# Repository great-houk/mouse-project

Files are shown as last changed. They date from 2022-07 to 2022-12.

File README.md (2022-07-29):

# Custom Mouse V1.0

This project is an all contains every piece you would need to fully order, assemble, and program a completely open source mouse.

This is only the first version of this mouse, and the end goal of this project is no where near complete. However, this first version does 100% work 90% of the time, so the inital goal of making a mouse is complete. In fact, I'm using it to write this readme. Pretty neat.

My immediate goal is to implement the wireless protocol over the SR1020 radio.

Future versions of this project won't use a barebones $15 dollar mouse off of amazon, and will have much higher quality everything, while also hopefully being cheaper. I used a lot of parts on this, like the MAX32625, because they looked cool. The 32625 has a one of a kind PMU, which is something like another set of super low power cores you can manually program through assembly. While this seems awesome at first, and like the perfect tool to reach extra efficient power targets, in the end the sensor draws >20mW anyway, so the difference of ~1-2mW the PMU provides is useless, and so it the extra cost.

# Notes for making your own

This is the mouse I bought and used as a base: [Amazon Link](https://www.amazon.com/gp/product/B07ZHFCM43/ref=ppx_yo_dt_b_search_asin_title?ie=UTF8&th=1)

For obtaining the other parts:
1. Most mouse parts can be desoldered from the mouse itself. I only bought one switch for the dongle off of digikey.
2. All other digital parts except the sensor can be obtained from digikey for reasonable prices, and the objects in the Kicad PCB should have digikey links associated with them already.
3. The mouse sensor is hard to get. If you are a student like me, you might be able to get a free sample from Pixart. If you aren't there are a couple of ebay postings or other second hand sellers which might offer them, but they take a while (>month normally) to ship. Pixart does offer to sell the sensors directly, but there is a minimum order quantity of 25.
4. I used JLCPCB to obtain the PCB. I had them make a stencil as well, in order to greatly simply to soldering process. For anyone in the US, chances are JLC is your best bet, for Europe, I've heard of other cheap PCB manufacturers which might do a better job, as long as the shipping isn't prohibitively expensive.
5. Programming the MCU. I used the [MCU Link](https://www.nxp.com/design/microcontrollers-developer-resources/mcu-link-debug-probe:MCU-LINK) with OpenOCD to program the chip, which had all the features I ended up needing. Maxim offers a custom fork of OpenOCD which comes the neccessary files for uploading to the MAX32625, and I made a simple custom file for the MCU Link, which is inside of the mouse folder. You need to place that file in the OpenOCD board config directory, and most online tutuorials should cover that.

The PCB is specifically designed around fitting in the mouse, and even then there were some mistakes I made. Most notably, the top right post hole was misplaced, so that needs to be cut flush so the PCB can rest flat. The antenna also sticks out the side, so you need to cut some small segments off of the casing in order to have it fit. Finally, the USB-C port is in a slightly lower and different place, so you need to cut the sides of the USB port out to have it fit and be accessible.

It took me many tries to assemble this properly, partially because it was my first time using solder past (which by the way is 100% what you need to use to solder this), and partially because there are no good resources out there for solder of this kind, at least that I could find. If you order the PCB from JLCPCB like I did, make sure to get a stencil, as it will make everything signifigantly easier. There is no need to order a stencil for the back, however, that only requires some careful soldering.

The most important parts when assembling the board are
1. Make sure you spread the paste over the stencil the fewest possible times, preferably in one strong, slow swipe. A good solder paste application makes this process signifigantly easier.
2. Don't leave the paste sitting for too long. You can take your time placing the parts, but after around 2-3 hours the paste will start drying and harden, making parts have a signifigantly higher risk of being blown away when using the heat gun.
3. Make sure to not have the temps too high. I broke my first few boards by creating shorts through burned flux. Don't do what I did.

And that's mostly it. There are other resources out there to help with the specifics, but that covers most of the general details.

# Project Structure

Each folder has it's own README which describes what it does, how it works, and how to use it, except the PCB.

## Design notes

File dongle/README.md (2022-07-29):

# Dongle

When the wireless protocal is implemented, this folder will serve as the source code for the dongle that communicates with the mouse, since no current PCs have UWB built in by default, afaik.

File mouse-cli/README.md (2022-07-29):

# Mouse CLI

Mouse CLI is a command line tool to interface with the mouse and it's custom command protocol. It has various commands, like bat to check battery voltage, or lorem-ipsum to check that both devices are working properly. 

In order to use, check the various commands available with the help command. This is a clap based CLI tool, so everything works like you would expect a normal CLI would.

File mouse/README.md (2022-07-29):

# Mouse

This is the main code repository for the mouse. This is what runs on the mouse and does literally everything. This directory contains several sub crates all of which implement and provide basic APIs to various MAX32625 features which where required to build this project. To change any functionality with the mouse or fix any bugs, this is where you want to be.

Goals:
1. The scroll wheel is currently rather buggy at any speed except medium, so possible come up with a better way to debounce/denoise the signals coming from the GPIOs.
2. Refactor, refactor, refactor. While the code in here isn't horrible, it isn't great. Many things could be rewritten in better and more efficient ways, especially the USB implementation.

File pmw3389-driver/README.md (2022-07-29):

# PMW3389 Driver

Like the SR1020 Driver, this provides a more generic implimentation of various methods used to communicate with and use the PMW3389 Mouse Sensor. There are many details in here which are limited because of the NDA which I signed to access them, so in order to understand why some things are the way they are, contact Pixart throught their support page to gain access to the datasheet and firmware.

For example, the ROM file is behind an NDA, so it is not included here, but is required for the code to compile.

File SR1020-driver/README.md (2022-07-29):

# SR1020

A currently not implemented driver for the SR1020 UWB radio. My goal for this is to draw inspiration from the [official spark SDK](https://www.sparkmicro.com/sdk-docs/), but provide lower level access to the hardware. It should be agnostic to whatever networking protocol you decide to implement on top of it. There is also an overall goal for this project to move everything from custom traits to embedded_hal traits, but currently I don't know if that's worth it.

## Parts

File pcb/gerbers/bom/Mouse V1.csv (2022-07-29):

Id | Designator | Package | Quantity | Designation | Supplier and ref
1 | C9,C3,C48,C46,C8,C47,C5,C30,C1,C45,C2,C7,C4,C29,C31,C10,C6 | C_0603_1608Metric | 17 | 1uF
2 | L5,L4 | L_0603_1608Metric | 2 | 180nH
3 | C25,C21,C23,C11 | C_0603_1608Metric | 4 | 4.7uF 10V
4 | R30,R21,R20,R19 | R_0603_1608Metric | 4 | 100K
5 | C41,C35 | C_0603_1608Metric | 2 | 680pF C0G NP0
6 | R6,R5,R3 | R_0603_1608Metric | 3 | 200
7 | R14 | R_0603_1608Metric | 1 | 10K
8 | C12,C28,C16,C17,C22,C27,C26,C37,C19 | C_0603_1608Metric | 9 | 10uF 10V
9 | U1,U6 | TSOT-23-5 | 2 | S-1740C33-M5T1U4
10 | Y2,Y3,Y1 | Crystal_SMD_3215-2Pin_3.2x1.5mm | 3 | ABS07-120-32.768KHZ-T
11 | FB2,FB3,FB5,FB1 | L_0805_2012Metric | 4 | FBMJ2125HS250NT
12 | U8,U5 | QFN-28-1EP_4x4mm_P0.4mm_EP2.6x2.6mm | 2 | SR1020-28QFN-TR
13 | R28,R33 | R_0603_1608Metric | 2 | 2.2M +- 1%
14 | R17,R18 | R_0603_1608Metric | 2 | 1M
15 | R16,R15 | R_0603_1608Metric | 2 | 5.1K
16 | C33,C42,C34,C43 | C_0603_1608Metric | 4 | 10pF
17 | R31,R32,R29 | R_0603_1608Metric | 3 | 390K +- 5%
18 | U4 | QFN40P400X400X80-29N | 1 | MAX8819CETI+
19 | C44,C38,C14,C13,C20,C15,C39,C18,C32 | C_0603_1608Metric | 9 | 100nF 10V
20 | R23 | R_0603_1608Metric | 1 | 120K
21 | U7 | SOIC-14_3.9x8.7mm_P1.27mm | 1 | ATSAMD11C14A-SS
22 | L2,L3,L1 | L_Taiyo-Yuden_MD-2020 | 3 | 4.7uH
23 | C36,C40 | C_0603_1608Metric | 2 | 68pF C0G NP0
24 | D5,D4 | CM1231-02SO | 2 | CM1231
25 | R26,R27 | R_0603_1608Metric | 2 | 470K
26 | R24 | R_0603_1608Metric | 1 | 80.6K
27 | U2 | MAX32625ITKL&plus_ | 1 | MAX32625
28 | R13 | R_0603_1608Metric | 1 | 13
29 | 3V3 | TestPoint_Pad_D1.0mm | 1 | 3.3V Test Point
30 | SW10 | SW_SPST_B3U-1000P-B | 1 | SW_Push
31 | C24 | C_0603_1608Metric | 1 | 2.2uF
32 | R25 | R_0603_1608Metric | 1 | 20K
33 | R22 | R_0603_1608Metric | 1 | 3K

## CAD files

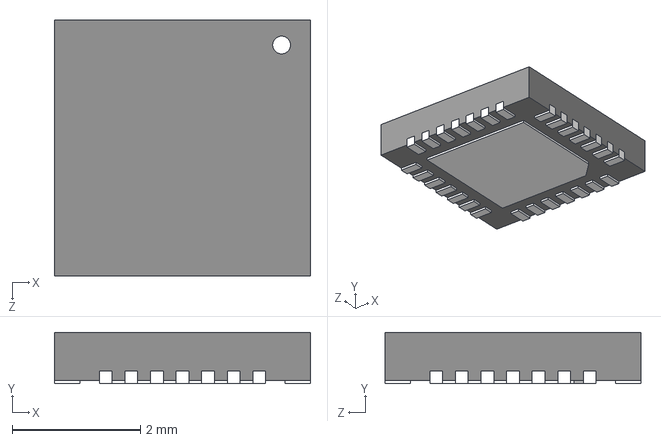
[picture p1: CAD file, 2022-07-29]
pcb/footprints/MAX8819/MAX8819CETI_.step
4.00 x 0.8 x 4.00 mm

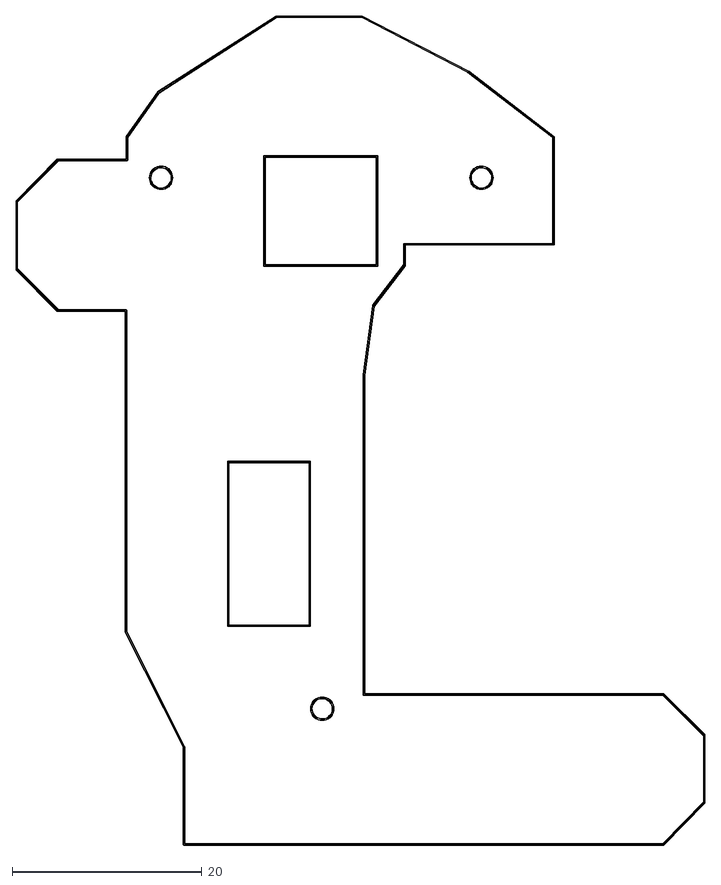
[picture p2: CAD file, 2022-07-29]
pcb/gerbers/gerbers/Mouse V1-Edge_Cuts.dxf
72.7 x 87.5

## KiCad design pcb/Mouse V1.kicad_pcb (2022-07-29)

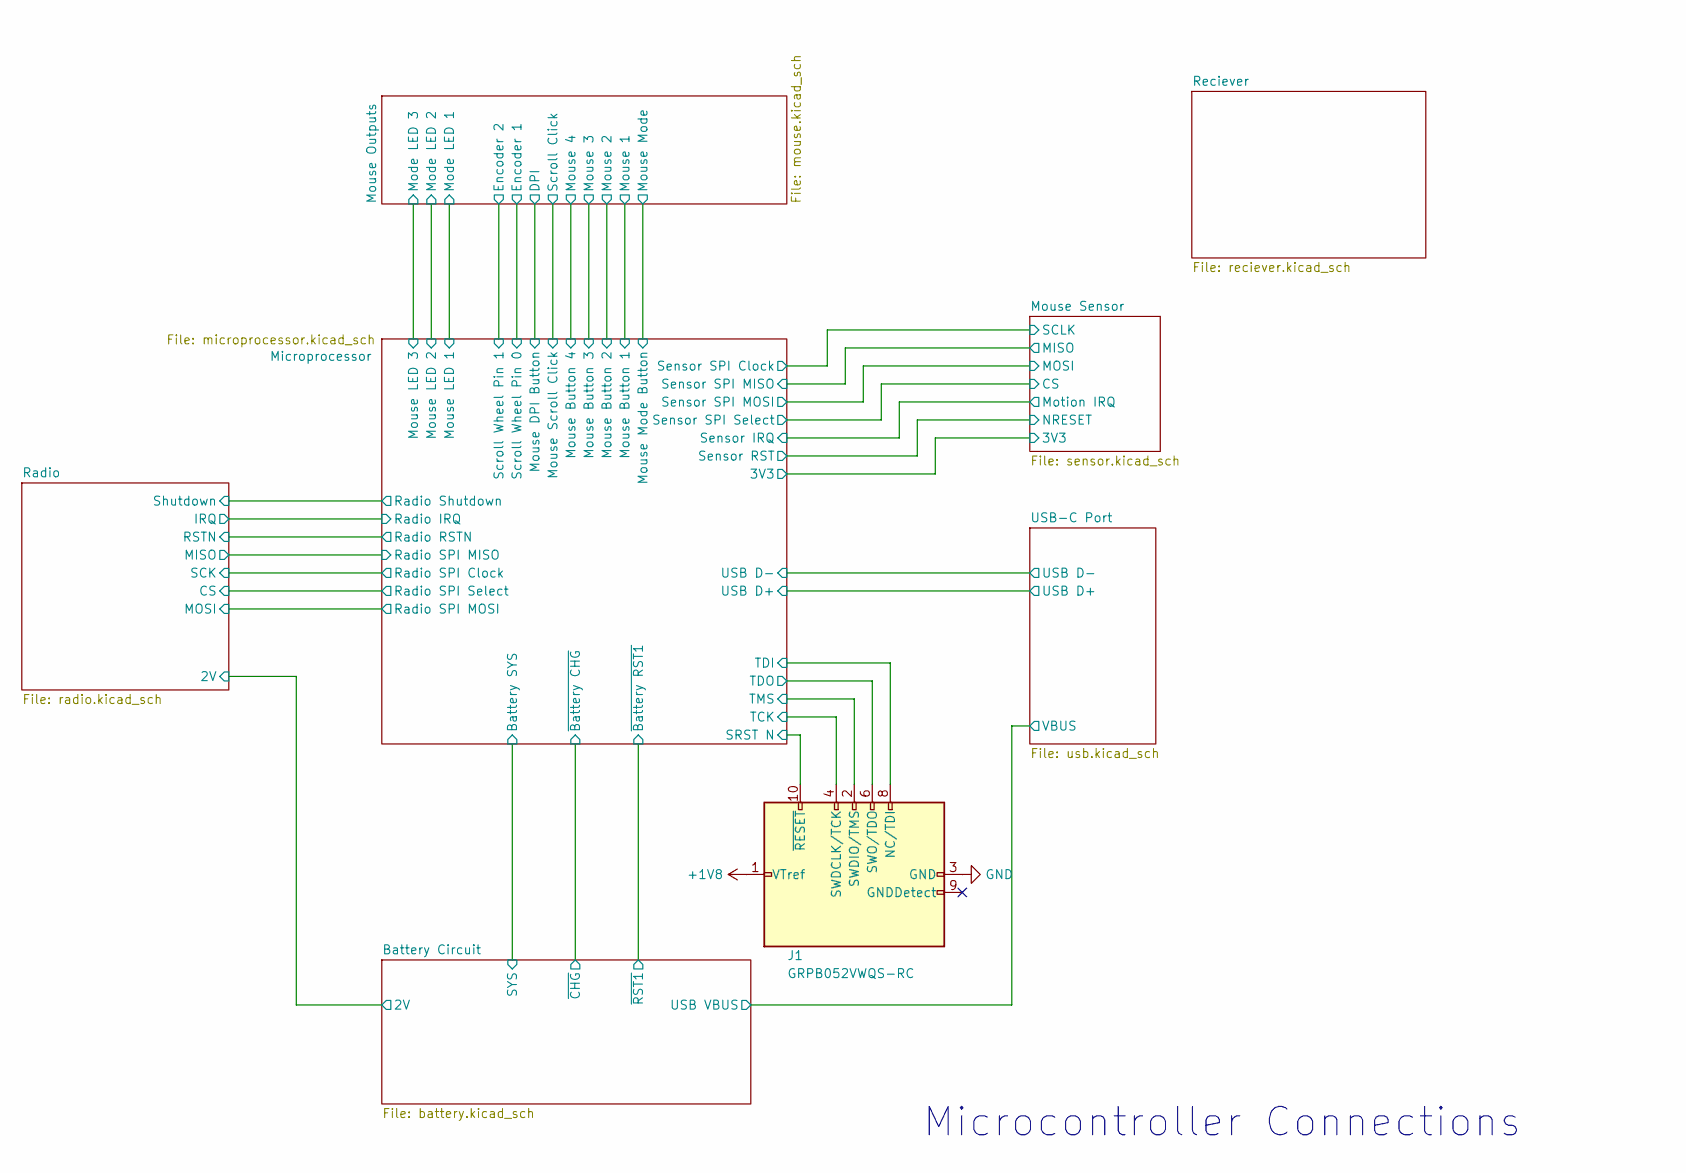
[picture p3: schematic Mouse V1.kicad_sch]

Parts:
J1: GRPB052VWQS-RC; PinHeader_2x05_P1.27mm_Vertical_SMD; DIGIKEY GRPB052VWQS-RC

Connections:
+1V8: J1.1 (VTref); also elsewhere on the board
/Microprocessor/SRST N: J1.10 (~RESET); also elsewhere on the board
/Microprocessor/TCK: J1.4 (SWDCLK/TCK); also elsewhere on the board
/Microprocessor/TDI: J1.8 (NC/TDI); also elsewhere on the board
/Microprocessor/TDO: J1.6 (SWO/TDO); also elsewhere on the board
/Microprocessor/TMS: J1.2 (SWDIO/TMS); also elsewhere on the board
GND: J1.3 (GND), J1.5 (GND); also elsewhere on the board

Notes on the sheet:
Microcontroller Connections

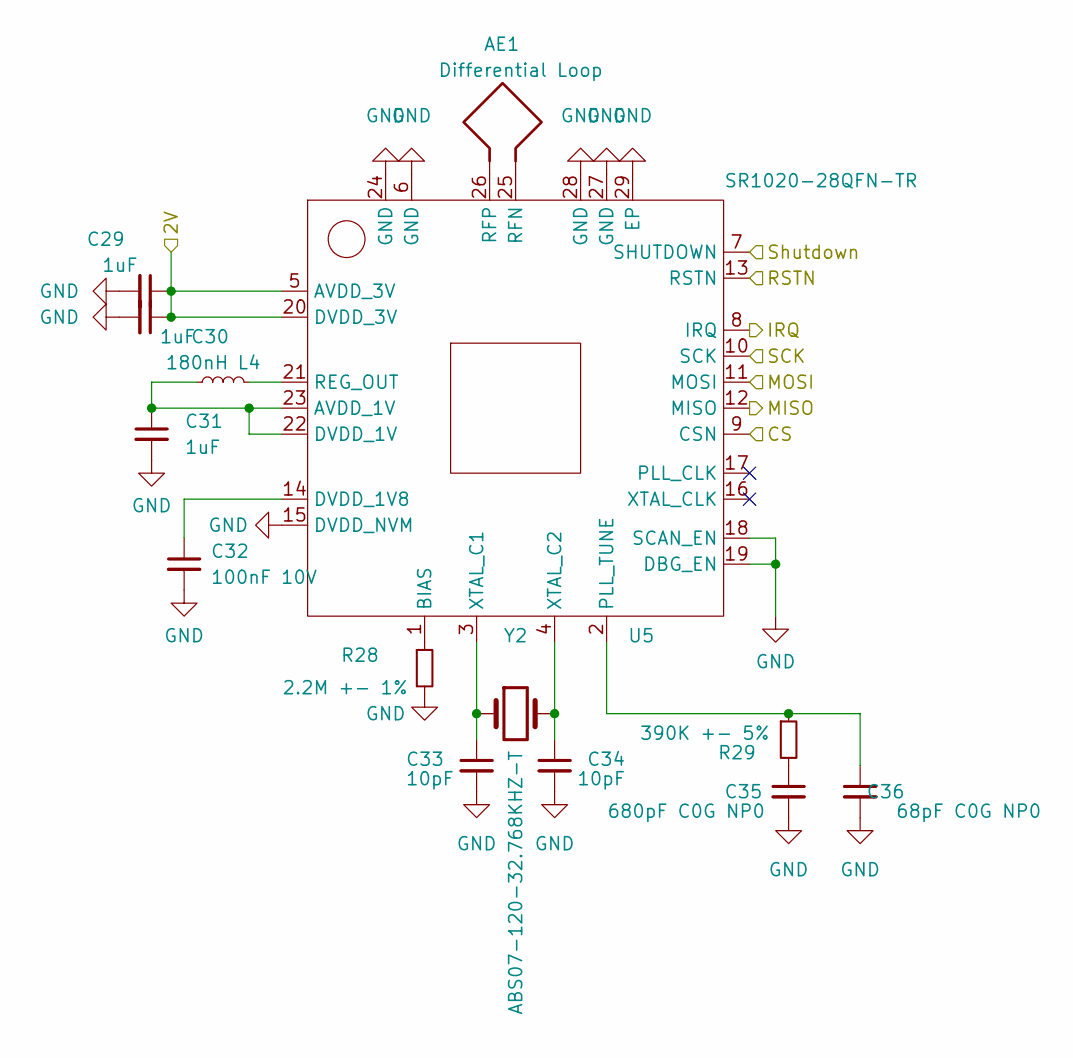
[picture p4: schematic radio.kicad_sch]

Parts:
AE1: Differential Loop; SR1020 Antenna Vivaldi
C29, C30, C31: 1uF; C_0603_1608Metric; DIGIKEY CL10A105KA8NNNC
C32: 100nF 10V; C_0603_1608Metric; DIGIKEY CL10B104KB8NNWC
C33, C34: 10pF; C_0603_1608Metric; DIGIKEY 06035A100JAT2A
C35: 680pF C0G NP0; C_0603_1608Metric; DIGIKEY 0603N681J500CT
C36: 68pF C0G NP0; C_0603_1608Metric; DIGIKEY CL10C680JB8NNNC
L4: 180nH; L_0603_1608Metric; DIGIKEY MLJ1608WR18JT000
R28: 2.2M +- 1%; R_0603_1608Metric; DIGIKEY RC0603FR-072M2L
R29: 390K +- 5%; R_0603_1608Metric; DIGIKEY RMCF0603JT390K
U5: SR1020-28QFN-TR; QFN-28-1EP_4x4mm_P0.4mm_EP2.6x2.6mm; DIGIKEY SR1020-28QFN-TR
Y2: ABS07-120-32.768KHZ-T; Crystal_SMD_3215-2Pin_3.2x1.5mm; DIGIKEY ABS07-120-32.768KHZ-T

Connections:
/Battery Circuit/2V: C29.1, C30.1, U5.5 (AVDD_3V), U5.20 (DVDD_3V); also elsewhere on the board
/Microprocessor/Radio IRQ: U5.8 (IRQ); also elsewhere on the board
/Microprocessor/Radio RSTN: U5.13 (RSTN); also elsewhere on the board
/Microprocessor/Radio SPI Clock: U5.10 (SCK); also elsewhere on the board
/Microprocessor/Radio SPI MISO: U5.12 (MISO); also elsewhere on the board
/Microprocessor/Radio SPI MOSI: U5.11 (MOSI); also elsewhere on the board
/Microprocessor/Radio SPI Select: U5.9 (CSN); also elsewhere on the board
/Microprocessor/Radio Shutdown: U5.7 (SHUTDOWN); also elsewhere on the board
GND: C29.2, C30.2, C31.2, C32.2, C33.2, C34.2, C35.2, C36.2, R28.2, U5.6 (GND), U5.15 (DVDD_NVM), U5.18 (SCAN_EN), U5.19 (DBG_EN), U5.24 (GND), U5.27 (GND), U5.28 (GND), U5.29 (EP); also elsewhere on the board
unnamed: AE1.1, U5.26 (RFP)
unnamed: AE1.2, U5.25 (RFN)
unnamed: C31.1, L4.1, U5.22 (DVDD_1V), U5.23 (AVDD_1V)
unnamed: C32.1, U5.14 (DVDD_1V8)
unnamed: C33.1, U5.3 (XTAL_C1), Y2.1
unnamed: C34.1, U5.4 (XTAL_C2), Y2.2
unnamed: C35.1, R29.2
unnamed: C36.1, R29.1, U5.2 (PLL_TUNE)
unnamed: L4.2, U5.21 (REG_OUT)
unnamed: R28.1, U5.1 (BIAS)

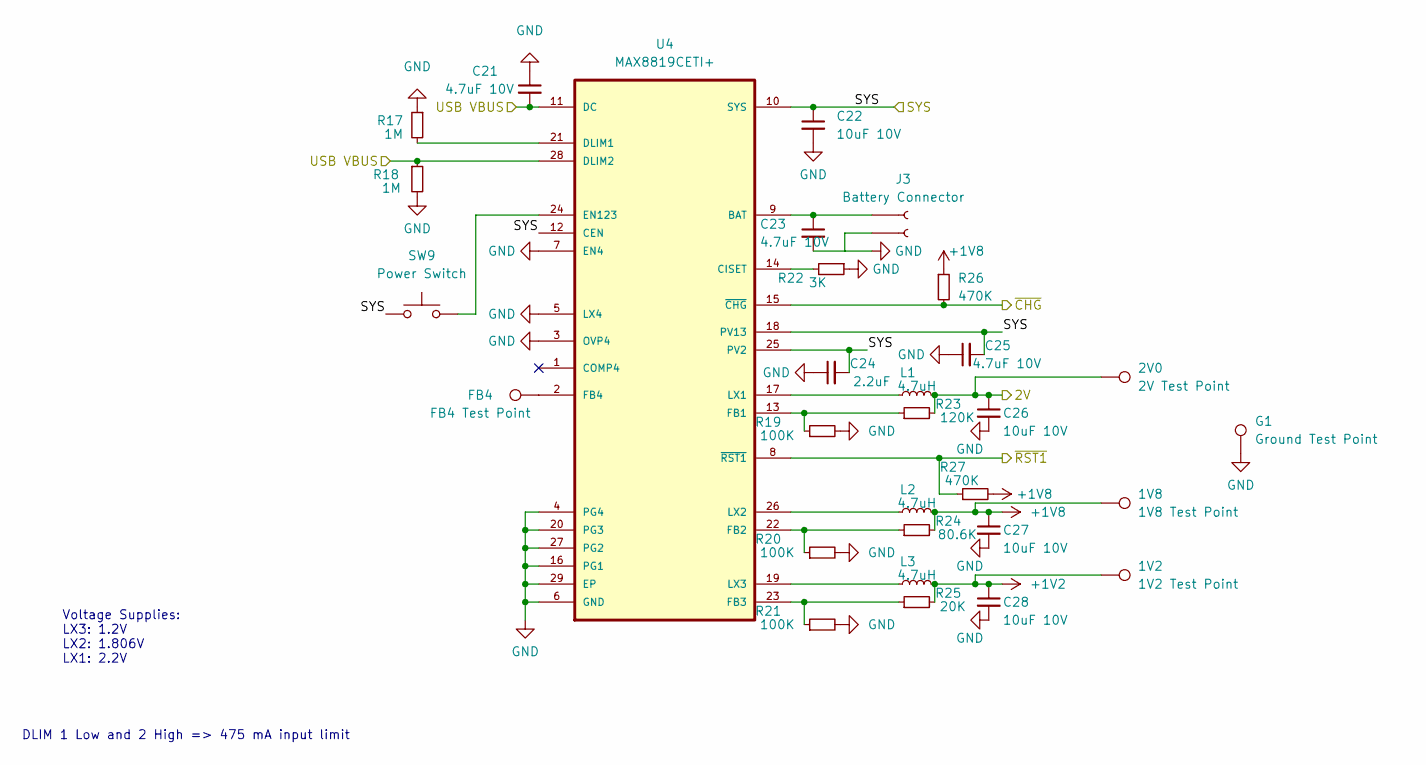
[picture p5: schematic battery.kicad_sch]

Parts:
1V2: 1V2 Test Point; TestPoint_Pad_D1.0mm
1V8: 1V8 Test Point; TestPoint_Pad_D1.0mm
2V0: 2V Test Point; TestPoint_Pad_D1.0mm
C21, C23, C25: 4.7uF 10V; C_0603_1608Metric; DIGIKEY CL10A475KP8NNNC
C22, C26, C27, C28: 10uF 10V; C_0603_1608Metric; DIGIKEY 0603ZD106KAT2A
C24: 2.2uF; C_0603_1608Metric; DIGIKEY CL10A225KP8NNNC
FB4: FB4 Test Point; TestPoint_Pad_D2.0mm
G1: Ground Test Point; TestPoint_Pad_D1.0mm
J3: Battery Connector; JST_PH_B2B-PH-K_1x02_P2.00mm_Vertical
L1, L2, L3: 4.7uH; L_Taiyo-Yuden_MD-2020; DIGIKEY VLS201612CX-4R7M-1
R17, R18: 1M; R_0603_1608Metric; DIGIKEY RMCF0603FT1M00
R19, R20, R21: 100K; R_0603_1608Metric; DIGIKEY RMCF0603FT100K
R22: 3K; R_0603_1608Metric; DIGIKEY RMCF0603JT3K00
R23: 120K; R_0603_1608Metric; DIGIKEY RMCF0603FT120K
R24: 80.6K; R_0603_1608Metric; DIGIKEY RMCF0603FT80K6
R25: 20K; R_0603_1608Metric; DIGIKEY RMCF0603FT20K0
R26, R27: 470K; R_0603_1608Metric; DIGIKEY RMCF0603JT470K
SW9: Power Switch; SW_SPDT_PCM12; DIGIKEY Have
U4: MAX8819CETI+; QFN40P400X400X80-29N; DIGIKEY MAX8819CETI+

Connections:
+1V2: 1V2.1, C28.1, L3.2, R25.2; also elsewhere on the board
+1V8: 1V8.1, C27.1, L2.2, R24.2, R26.1, R27.2; also elsewhere on the board
/Battery Circuit/2V: 2V0.1, C26.1, L1.2, R23.2; also elsewhere on the board
/Battery Circuit/SYS: C22.1, C24.2, C25.2, SW9.1, U4.10 (SYS), U4.12 (CEN), U4.18 (PV13), U4.25 (PV2); also elsewhere on the board
/Battery Circuit/USB VBUS: C21.2, R18.1, U4.11 (DC), U4.28 (DLIM2); also elsewhere on the board
/Battery Circuit/~CHG: R26.2, U4.15 (~CHG); also elsewhere on the board
/Battery Circuit/~RST1: R27.1, U4.8 (~RST1); also elsewhere on the board
GND: C21.1, C22.2, C23.2, C24.1, C25.1, C26.2, C27.2, C28.2, G1.1, J3.1, R17.1, R18.2, R19.2, R20.2, R21.2, R22.1, U4.3 (OVP4), U4.4 (PG4), U4.5 (LX4), U4.6 (GND), U4.7 (EN4), U4.16 (PG1), U4.20 (PG3), U4.27 (PG2), U4.29 (EP); also elsewhere on the board
unnamed: C23.1, J3.2, U4.9 (BAT)
unnamed: FB4.1, U4.2 (FB4)
unnamed: L1.1, U4.17 (LX1)
unnamed: L2.1, U4.26 (LX2)
unnamed: L3.1, U4.19 (LX3)
unnamed: R17.2, U4.21 (DLIM1)
unnamed: R19.1, R23.1, U4.13 (FB1)
unnamed: R20.1, R24.1, U4.22 (FB2)
unnamed: R21.1, R25.1, U4.23 (FB3)
unnamed: R22.2, U4.14 (CISET)
unnamed: SW9.2, U4.24 (EN123)

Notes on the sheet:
DLIM 1 Low and 2 High => 475 mA input limit
Voltage Supplies: LX3: 1.2V LX2: 1.806V LX1: 2.2V

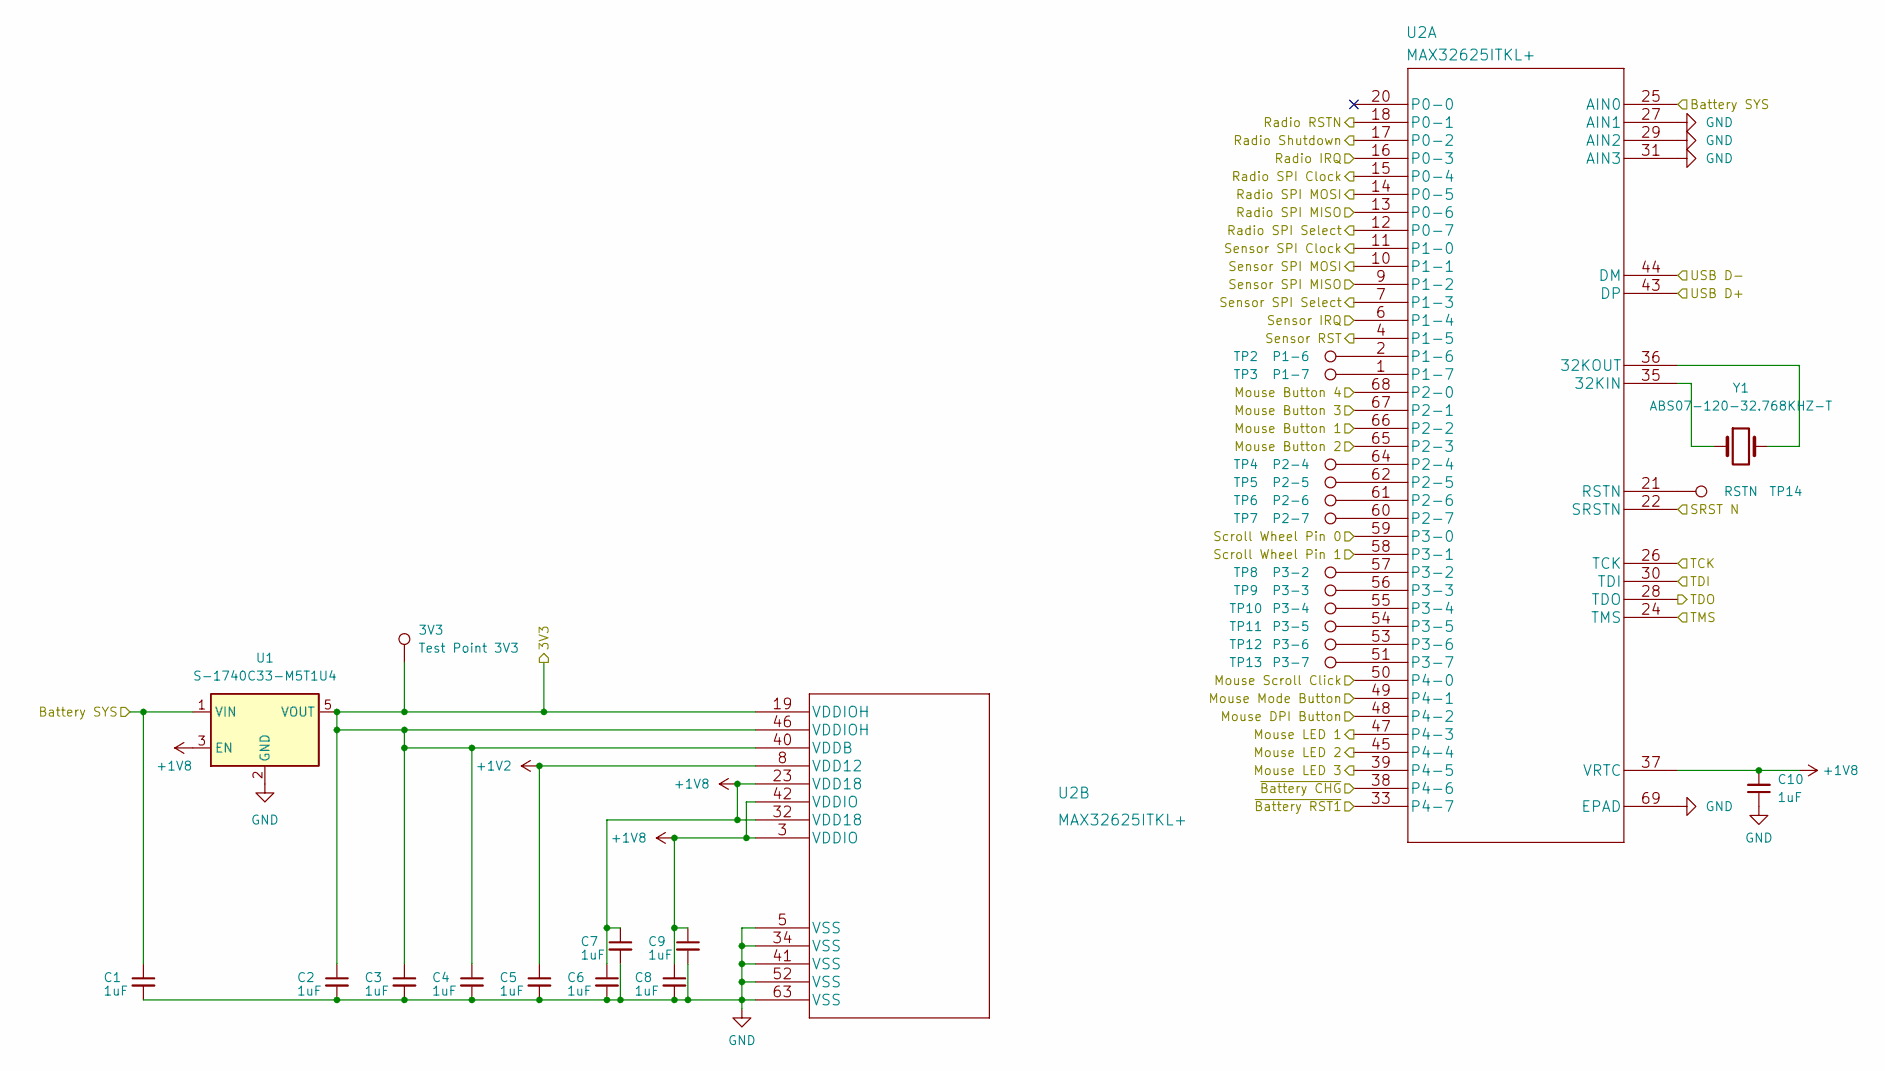
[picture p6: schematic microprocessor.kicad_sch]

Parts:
3V3: Test Point 3V3; TestPoint_Pad_D1.0mm
C1, C2, C3, C4, C5, C6, C7, C8, C9, C10: 1uF; C_0603_1608Metric; DIGIKEY CL10A105KA8NNNC
TP2: P1-6; TestPoint_Pad_D1.0mm
TP3: P1-7; TestPoint_Pad_D1.0mm
TP4: P2-4; TestPoint_Pad_D1.0mm
TP5: P2-5; TestPoint_Pad_D1.0mm
TP6: P2-6; TestPoint_Pad_D1.0mm
TP7: P2-7; TestPoint_Pad_D1.0mm
TP8: P3-2; TestPoint_Pad_D1.0mm
TP9: P3-3; TestPoint_Pad_D1.0mm
TP10: P3-4; TestPoint_Pad_D1.0mm
TP11: P3-5; TestPoint_Pad_D1.0mm
TP12: P3-6; TestPoint_Pad_D1.0mm
TP13: P3-7; TestPoint_Pad_D1.0mm
TP14: RSTN; TestPoint_Pad_D1.0mm
U1: S-1740C33-M5T1U4; TSOT-23-5; DIGIKEY S-1740C33-M5T1U4
U2: MAX32625ITKL+; MAX32625ITKL&plus_; DIGIKEY MAX32625ITKL+
Y1: ABS07-120-32.768KHZ-T; Crystal_SMD_3215-2Pin_3.2x1.5mm; DIGIKEY ABS07-120-32.768KHZ-T

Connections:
+1V2: C5.1, U2.8 (VDD12); also elsewhere on the board
+1V8: C6.1, C7.1, C8.1, C9.1, C10.2, U1.3 (EN), U2.3 (VDDIO), U2.23 (VDD18), U2.32 (VDD18), U2.37 (VRTC), U2.42 (VDDIO); also elsewhere on the board
/Battery Circuit/SYS: C1.1, U1.1 (VIN), U2.25 (AIN0); also elsewhere on the board
/Battery Circuit/~CHG: U2.38 (P4-6); also elsewhere on the board
/Battery Circuit/~RST1: U2.33 (P4-7); also elsewhere on the board
/Microprocessor/3V3: 3V3.1, C2.1, C3.1, C4.1, U1.5 (VOUT), U2.19 (VDDIOH), U2.40 (VDDB), U2.46 (VDDIOH); also elsewhere on the board
/Microprocessor/Mouse Button 1: U2.66 (P2-2); also elsewhere on the board
/Microprocessor/Mouse Button 2: U2.65 (P2-3); also elsewhere on the board
/Microprocessor/Mouse Button 3: U2.67 (P2-1); also elsewhere on the board
/Microprocessor/Mouse Button 4: U2.68 (P2-0); also elsewhere on the board
/Microprocessor/Mouse DPI Button: U2.48 (P4-2); also elsewhere on the board
/Microprocessor/Mouse LED 1: U2.47 (P4-3); also elsewhere on the board
/Microprocessor/Mouse LED 2: U2.45 (P4-4); also elsewhere on the board
/Microprocessor/Mouse LED 3: U2.39 (P4-5); also elsewhere on the board
/Microprocessor/Mouse Mode Button: U2.49 (P4-1); also elsewhere on the board
/Microprocessor/Mouse Scroll Click: U2.50 (P4-0); also elsewhere on the board
/Microprocessor/Radio IRQ: U2.16 (P0-3); also elsewhere on the board
/Microprocessor/Radio RSTN: U2.18 (P0-1); also elsewhere on the board
/Microprocessor/Radio SPI Clock: U2.15 (P0-4); also elsewhere on the board
/Microprocessor/Radio SPI MISO: U2.13 (P0-6); also elsewhere on the board
/Microprocessor/Radio SPI MOSI: U2.14 (P0-5); also elsewhere on the board
/Microprocessor/Radio SPI Select: U2.12 (P0-7); also elsewhere on the board
/Microprocessor/Radio Shutdown: U2.17 (P0-2); also elsewhere on the board
/Microprocessor/SRST N: U2.22 (SRSTN); also elsewhere on the board
/Microprocessor/Scroll Wheel Pin 0: U2.59 (P3-0); also elsewhere on the board
/Microprocessor/Scroll Wheel Pin 1: U2.58 (P3-1); also elsewhere on the board
/Microprocessor/Sensor IRQ: U2.6 (P1-4); also elsewhere on the board
/Microprocessor/Sensor RST: U2.4 (P1-5); also elsewhere on the board
/Microprocessor/Sensor SPI Clock: U2.11 (P1-0); also elsewhere on the board
/Microprocessor/Sensor SPI MISO: U2.9 (P1-2); also elsewhere on the board
/Microprocessor/Sensor SPI MOSI: U2.10 (P1-1); also elsewhere on the board
/Microprocessor/Sensor SPI Select: U2.7 (P1-3); also elsewhere on the board
/Microprocessor/TCK: U2.26 (TCK); also elsewhere on the board
/Microprocessor/TDI: U2.30 (TDI); also elsewhere on the board
/Microprocessor/TDO: U2.28 (TDO); also elsewhere on the board
/Microprocessor/TMS: U2.24 (TMS); also elsewhere on the board
/Microprocessor/USB D+: U2.43 (DP); also elsewhere on the board
/Microprocessor/USB D-: U2.44 (DM); also elsewhere on the board
GND: C1.2, C2.2, C3.2, C4.2, C5.2, C6.2, C7.2, C8.2, C9.2, C10.1, U1.2 (GND), U2.5 (VSS), U2.27 (AIN1), U2.29 (AIN2), U2.31 (AIN3), U2.34 (VSS), U2.41 (VSS), U2.52 (VSS), U2.63 (VSS), U2.69 (EPAD); also elsewhere on the board
unnamed: TP2.1, U2.2 (P1-6)
unnamed: TP3.1, U2.1 (P1-7)
unnamed: TP4.1, U2.64 (P2-4)
unnamed: TP5.1, U2.62 (P2-5)
unnamed: TP6.1, U2.61 (P2-6)
unnamed: TP7.1, U2.60 (P2-7)
unnamed: TP8.1, U2.57 (P3-2)
unnamed: TP9.1, U2.56 (P3-3)
unnamed: TP10.1, U2.55 (P3-4)
unnamed: TP11.1, U2.54 (P3-5)
unnamed: TP12.1, U2.53 (P3-6)
unnamed: TP13.1, U2.51 (P3-7)
unnamed: TP14.1, U2.21 (RSTN)
unnamed: U2.35 (32KIN), Y1.1
unnamed: U2.36 (32KOUT), Y1.2

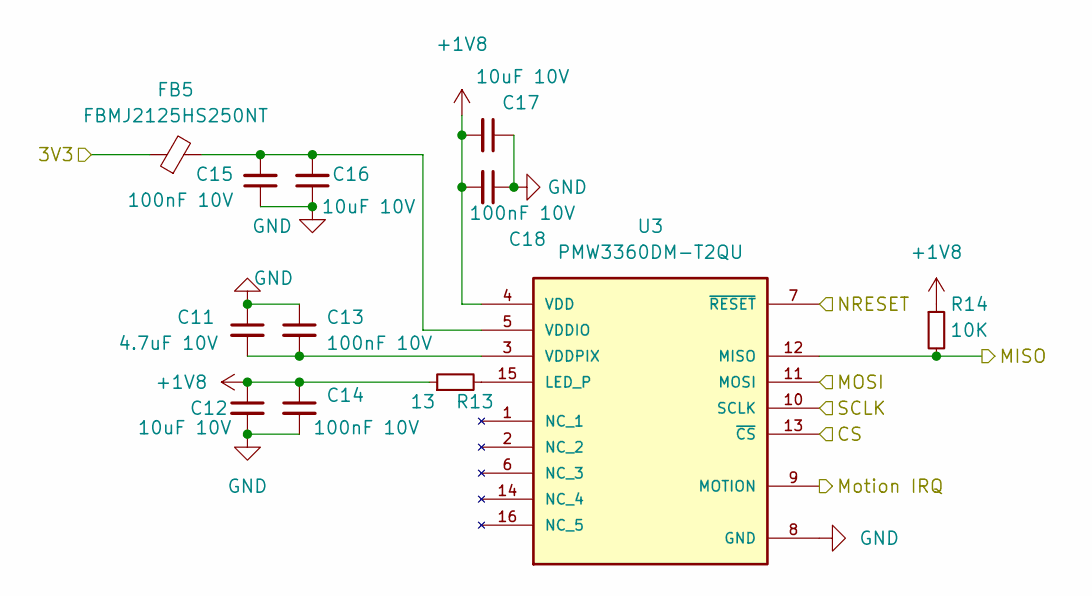
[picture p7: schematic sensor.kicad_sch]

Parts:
C11: 4.7uF 10V; C_0603_1608Metric; DIGIKEY CL10A475KP8NNNC
C12, C16, C17: 10uF 10V; C_0603_1608Metric; DIGIKEY 0603ZD106KAT2A
C13, C14, C15, C18: 100nF 10V; C_0603_1608Metric; DIGIKEY CL10B104KB8NNWC
FB5: FBMJ2125HS250NT; L_0805_2012Metric; DIGIKEY FBMJ2125HS250NT
R13: 13; R_0603_1608Metric; DIGIKEY RMCF0603FT13R0
R14: 10K; R_0603_1608Metric; DIGIKEY RNCP0603FTD10K0
U3: PMW3360DM-T2QU; MANUFACTURER_PART_NUMBER PMW3360DM-T2QU; DIGIKEY PMW3360DM-T2QU

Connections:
+1V8: C12.1, C14.1, C17.2, C18.2, R13.1, R14.1, U3.4 (VDD); also elsewhere on the board
/Microprocessor/3V3: FB5.1; also elsewhere on the board
/Microprocessor/Sensor IRQ: U3.9 (MOTION); also elsewhere on the board
/Microprocessor/Sensor RST: U3.7 (~RESET); also elsewhere on the board
/Microprocessor/Sensor SPI Clock: U3.10 (SCLK); also elsewhere on the board
/Microprocessor/Sensor SPI MISO: R14.2, U3.12 (MISO); also elsewhere on the board
/Microprocessor/Sensor SPI MOSI: U3.11 (MOSI); also elsewhere on the board
/Microprocessor/Sensor SPI Select: U3.13 (~CS); also elsewhere on the board
GND: C11.1, C12.2, C13.1, C14.2, C15.1, C16.1, C17.1, C18.1, U3.8 (GND); also elsewhere on the board
unnamed: C11.2, C13.2, U3.3 (VDDPIX)
unnamed: C15.2, C16.2, FB5.2, U3.5 (VDDIO)
unnamed: R13.2, U3.15 (LED_P)

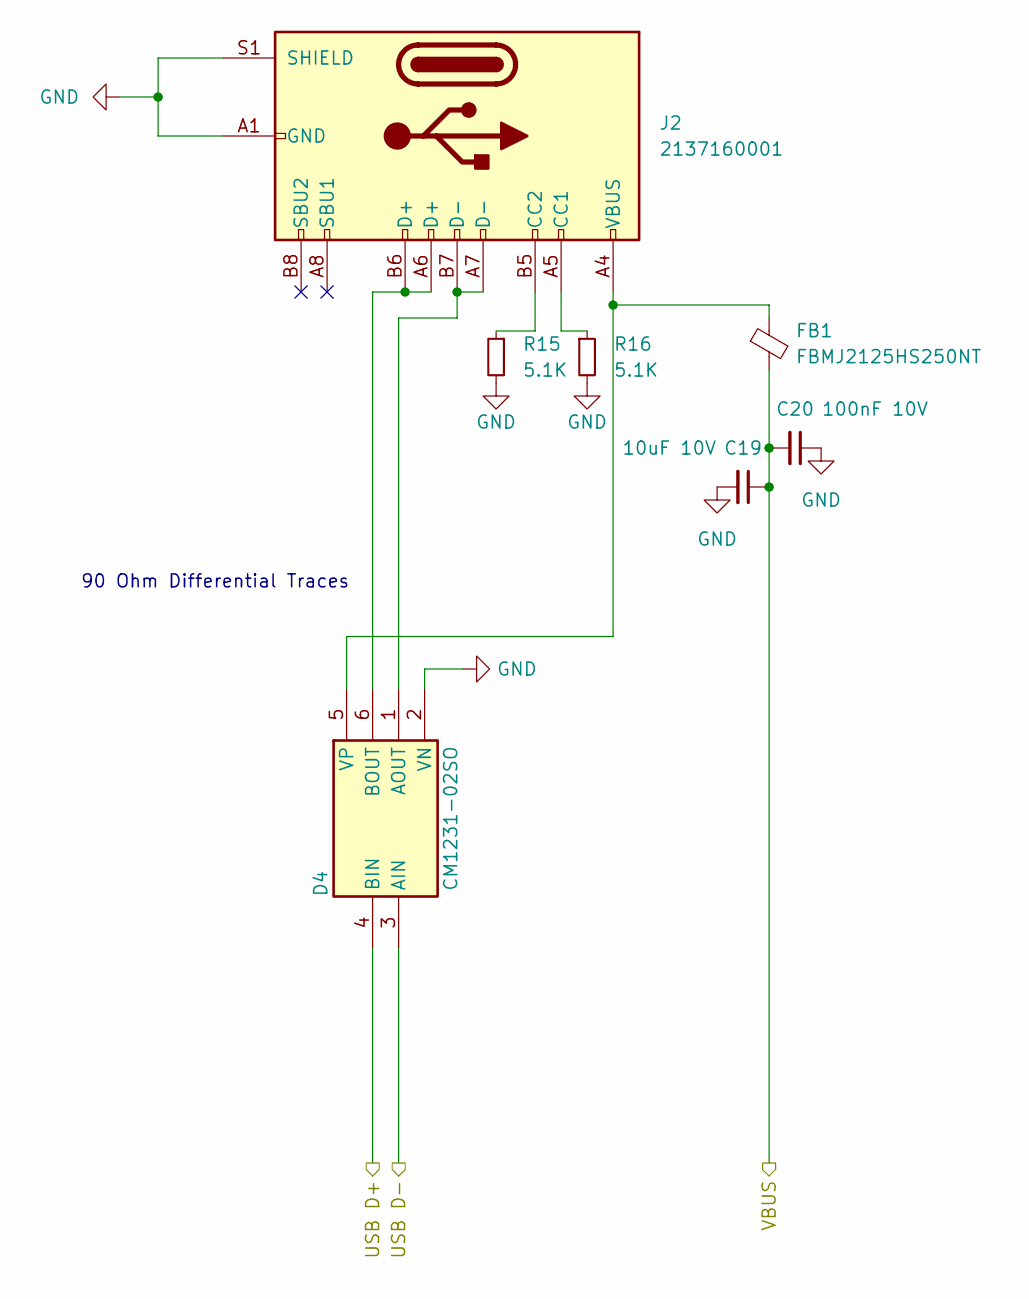
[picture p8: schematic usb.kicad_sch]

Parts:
C19: 10uF 10V; C_0603_1608Metric; DIGIKEY 0603ZD106KAT2A
C20: 100nF 10V; C_0603_1608Metric; DIGIKEY CL10B104KB8NNWC
D4: CM1231-02SO; Standoff Voltage 5V; Manufacturer Part Number CM1231-02SO; DIGIKEY CM1231-02SO
FB1: FBMJ2125HS250NT; L_0805_2012Metric; DIGIKEY FBMJ2125HS250NT
J2: 2137160001; USB_C_Receptacle_JAE_DX07S016JA1R1500; DIGIKEY 2137160001
R15, R16: 5.1K; R_0603_1608Metric; DIGIKEY RMCF0603JT5K10

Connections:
/Battery Circuit/USB VBUS: C19.1, C20.2, FB1.2; also elsewhere on the board
/Microprocessor/USB D+: D4.4 (BIN); also elsewhere on the board
/Microprocessor/USB D-: D4.3 (AIN); also elsewhere on the board
GND: C19.2, C20.1, D4.2 (VN), J2.A1 (GND), J2.A12 (GND), J2.B1 (GND), J2.B12 (GND), J2.S1 (SHIELD), R15.2, R16.2; also elsewhere on the board
unnamed: D4.1 (AOUT), J2.A7 (D-), J2.B7 (D-)
unnamed: D4.5 (VP), FB1.1, J2.A4 (VBUS), J2.A9 (VBUS), J2.B4 (VBUS), J2.B9 (VBUS)
unnamed: D4.6 (BOUT), J2.A6 (D+), J2.B6 (D+)
unnamed: J2.A5 (CC1), R16.1
unnamed: J2.B5 (CC2), R15.1

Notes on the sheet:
90 Ohm Differential Traces

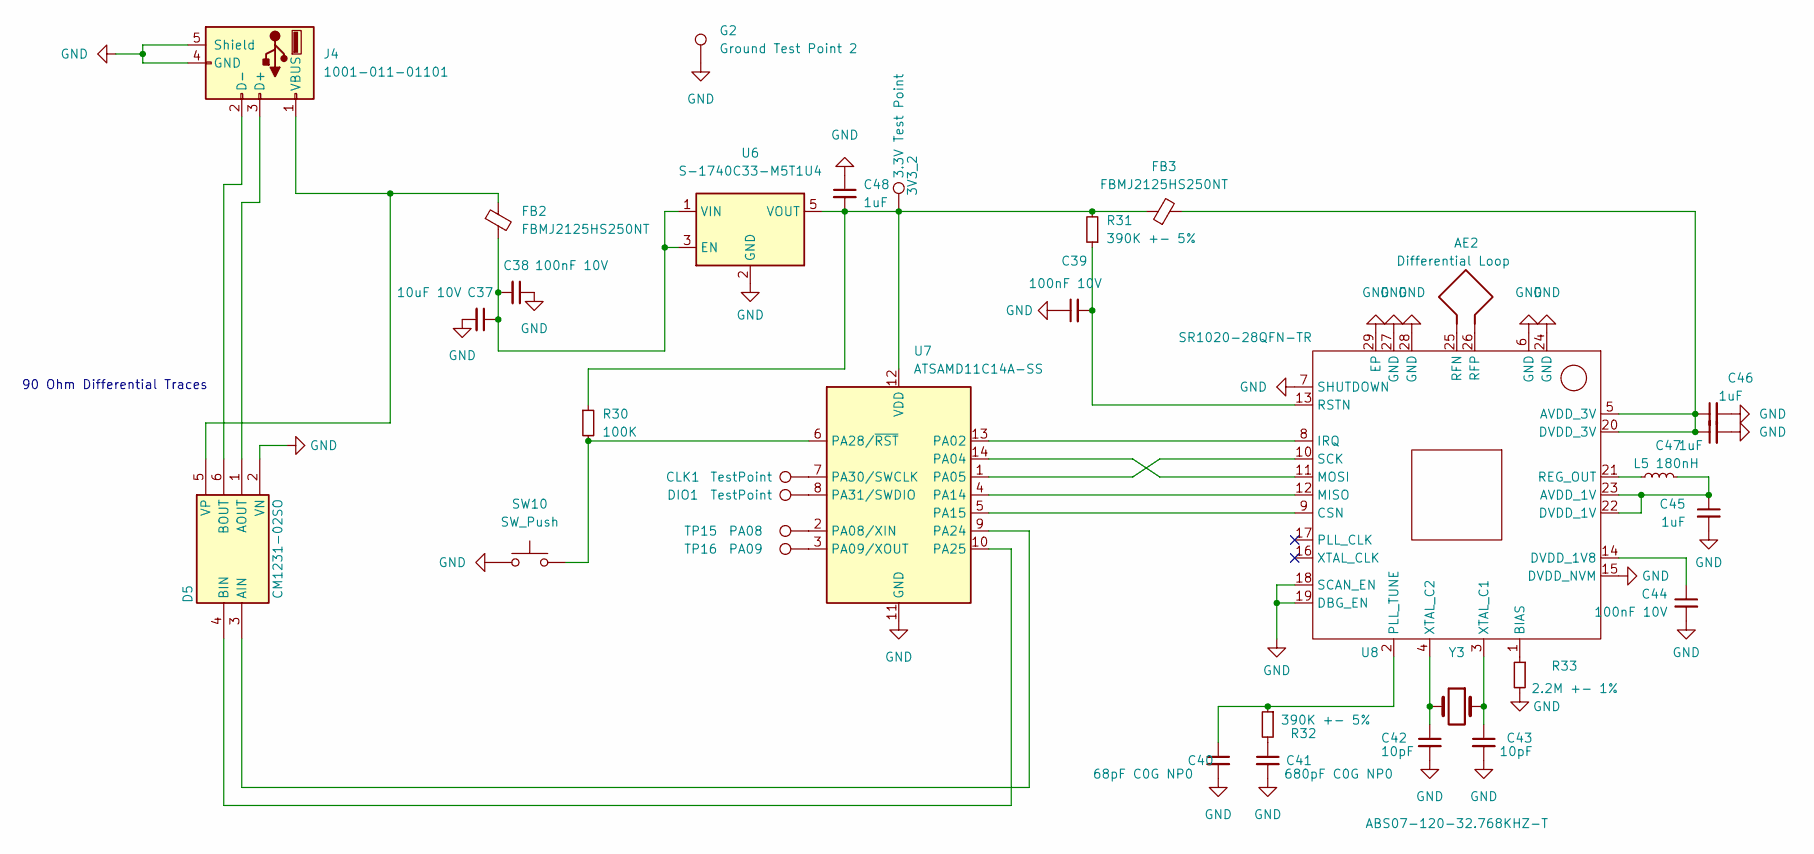
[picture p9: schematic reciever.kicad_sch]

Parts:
3V3_2: 3.3V Test Point; TestPoint_Pad_D1.0mm
AE2: Differential Loop; SR1020 Antenna Vivaldi
C37: 10uF 10V; C_0603_1608Metric; DIGIKEY 0603ZD106KAT2A
C38, C39, C44: 100nF 10V; C_0603_1608Metric; DIGIKEY CL10B104KB8NNWC
C40: 68pF C0G NP0; C_0603_1608Metric; DIGIKEY CL10C680JB8NNNC
C41: 680pF C0G NP0; C_0603_1608Metric; DIGIKEY 0603N681J500CT
C42, C43: 10pF; C_0603_1608Metric; DIGIKEY 06035A100JAT2A
C45, C46, C47, C48: 1uF; C_0603_1608Metric; DIGIKEY CL10A105KA8NNNC
CLK1: TestPoint; TestPoint_Pad_D1.0mm
D5: CM1231-02SO; Standoff Voltage 5V; Manufacturer Part Number CM1231-02SO; DIGIKEY CM1231-02SO
DIO1: TestPoint; TestPoint_Pad_D1.0mm
FB2, FB3: FBMJ2125HS250NT; L_0805_2012Metric; DIGIKEY FBMJ2125HS250NT
G2: Ground Test Point 2; TestPoint_Pad_D1.0mm
J4: 1001-011-01101; USB_A_CNCTech_1001-011-01101_Horizontal; DIGIKEY 1001-011-01101
L5: 180nH; L_0603_1608Metric; DIGIKEY MLJ1608WR18JT000
R30: 100K; R_0603_1608Metric; DIGIKEY RMCF0603FT100K
R31, R32: 390K +- 5%; R_0603_1608Metric; DIGIKEY RMCF0603JT390K
R33: 2.2M +- 1%; R_0603_1608Metric; DIGIKEY RC0603FR-072M2L
SW10: SW_Push; SW_SPST_B3U-1000P-B; DIGIKEY B3U-1000P-B
TP15: PA08; TestPoint_Pad_D1.0mm
TP16: PA09; TestPoint_Pad_D1.0mm
U6: S-1740C33-M5T1U4; TSOT-23-5; DIGIKEY S-1740C33-M5T1U4
U7: ATSAMD11C14A-SS; SOIC-14_3.9x8.7mm_P1.27mm; DIGIKEY ATSAMD11C14A-SS
U8: SR1020-28QFN-TR; QFN-28-1EP_4x4mm_P0.4mm_EP2.6x2.6mm; DIGIKEY SR1020-28QFN-TR
Y3: ABS07-120-32.768KHZ-T; Crystal_SMD_3215-2Pin_3.2x1.5mm; DIGIKEY ABS07-120-32.768KHZ-T

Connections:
GND: C37.2, C38.1, C39.1, C40.2, C41.2, C42.2, C43.2, C44.2, C45.2, C46.2, C47.2, C48.1, D5.2 (VN), G2.1, J4.4 (GND), J4.5 (Shield), R33.2, SW10.1, U6.2 (GND), U7.11 (GND), U8.6 (GND), U8.7 (SHUTDOWN), U8.15 (DVDD_NVM), U8.18 (SCAN_EN), U8.19 (DBG_EN), U8.24 (GND), U8.27 (GND), U8.28 (GND), U8.29 (EP); also elsewhere on the board
unnamed 41: 3V3_2.1, C48.2, FB3.1, R30.1, R31.2, U6.5 (VOUT), U7.12 (VDD); also elsewhere on the board
unnamed: AE2.1, U8.26 (RFP)
unnamed: AE2.2, U8.25 (RFN)
unnamed: C37.1, C38.2, FB2.2, U6.1 (VIN), U6.3 (EN)
unnamed: C39.2, R31.1, U8.13 (RSTN)
unnamed: C40.1, R32.1, U8.2 (PLL_TUNE)
unnamed: C41.1, R32.2
unnamed: C42.1, U8.4 (XTAL_C2), Y3.2
unnamed: C43.1, U8.3 (XTAL_C1), Y3.1
unnamed: C44.1, U8.14 (DVDD_1V8)
unnamed: C45.1, L5.1, U8.22 (DVDD_1V), U8.23 (AVDD_1V)
unnamed: C46.1, C47.1, FB3.2, U8.5 (AVDD_3V), U8.20 (DVDD_3V)
unnamed 64: CLK1.1, U7.7 (PA30/SWCLK); also elsewhere on the board
unnamed: D5.1 (AOUT), J4.3 (D+)
unnamed: D5.3 (AIN), U7.9 (PA24)
unnamed: D5.4 (BIN), U7.10 (PA25)
unnamed: D5.5 (VP), FB2.1, J4.1 (VBUS)
unnamed: D5.6 (BOUT), J4.2 (D-)
unnamed 76: DIO1.1, U7.8 (PA31/SWDIO); also elsewhere on the board
unnamed: L5.2, U8.21 (REG_OUT)
unnamed: R30.2, SW10.2, U7.6 (PA28/~RST)
unnamed: R33.1, U8.1 (BIAS)
unnamed: TP15.1, U7.2 (PA08/XIN)
unnamed: TP16.1, U7.3 (PA09/XOUT)
unnamed: U7.1 (PA05), U8.10 (SCK)
unnamed: U7.4 (PA14), U8.12 (MISO)
unnamed: U7.5 (PA15), U8.9 (CSN)
unnamed: U7.13 (PA02), U8.8 (IRQ)
unnamed: U7.14 (PA04), U8.11 (MOSI)

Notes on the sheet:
90 Ohm Differential Traces

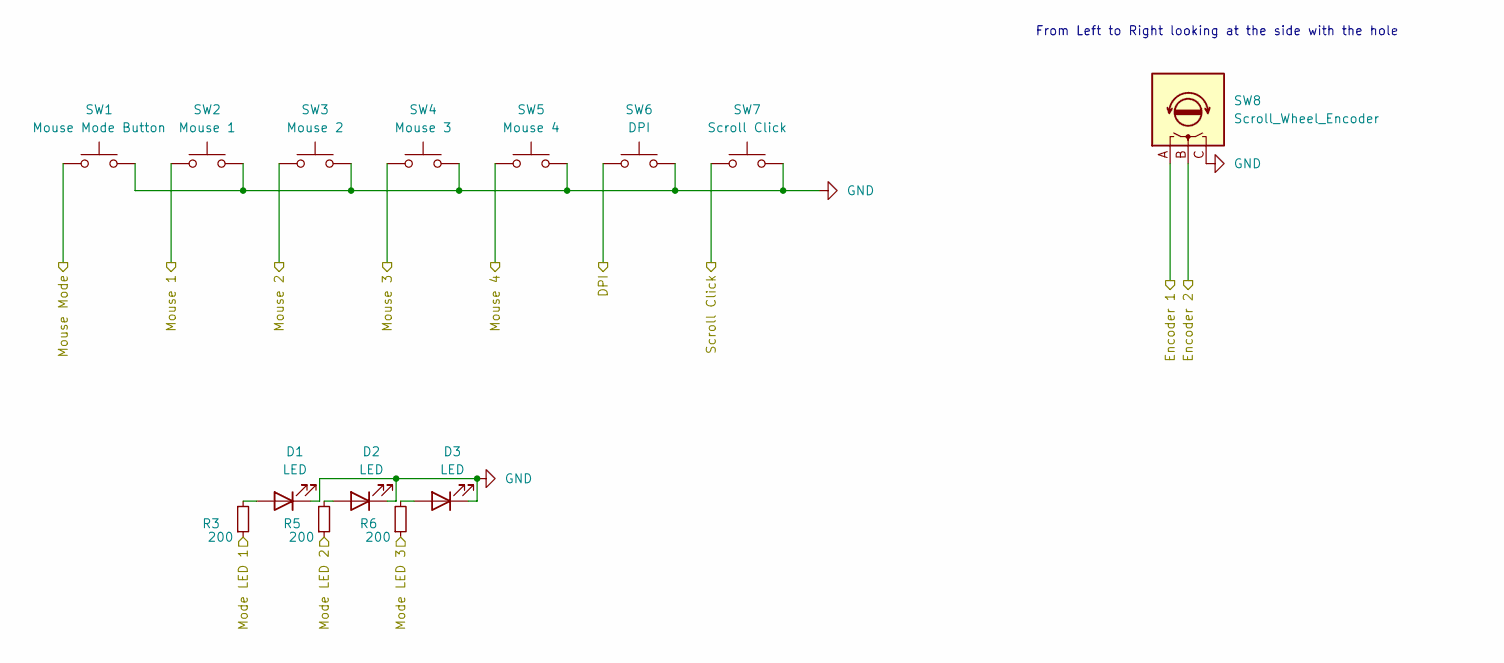
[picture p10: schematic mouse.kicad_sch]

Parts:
D1: LED; LED_0603_1608Metric; DIGIKEY LTST-C191KFKT
D2: LED; LED_0603_1608Metric; DIGIKEY LTST-C191KRKT
D3: LED; LED_0603_1608Metric; DIGIKEY LTST-C191KGKT
R3, R5, R6: 200; R_0603_1608Metric; DIGIKEY RNCP0603FTD200R
SW1: Mouse Mode Button; SW_PUSH_6mm; DIGIKEY Have
SW2: Mouse 1; TL59AF100Q; DIGIKEY Have
SW3: Mouse 2; TL59AF100Q; DIGIKEY Have
SW4: Mouse 3; TL59AF100Q; DIGIKEY Have
SW5: Mouse 4; TL59AF100Q; DIGIKEY Have
SW6: DPI; TL59AF100Q; DIGIKEY Have
SW7: Scroll Click; D2F-01L; DIGIKEY Have
SW8: Scroll_Wheel_Encoder; Encoder; DIGIKEY Have

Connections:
/Microprocessor/Mouse Button 2: SW3.1; also elsewhere on the board
/Microprocessor/Mouse Button 3: SW4.1; also elsewhere on the board
/Microprocessor/Mouse Button 4: SW5.1; also elsewhere on the board
/Microprocessor/Mouse DPI Button: SW6.1; also elsewhere on the board
/Microprocessor/Mouse LED 1: R3.1; also elsewhere on the board
/Microprocessor/Mouse LED 2: R5.1; also elsewhere on the board
/Microprocessor/Mouse LED 3: R6.1; also elsewhere on the board
/Microprocessor/Mouse Mode Button: SW1.1; also elsewhere on the board
/Microprocessor/Scroll Wheel Pin 0: SW8.A; also elsewhere on the board
/Microprocessor/Scroll Wheel Pin 1: SW8.B; also elsewhere on the board
GND: D1.1 (K), D2.1 (K), D3.1 (K), SW1.2, SW2.2, SW3.2, SW4.2, SW5.2, SW6.2, SW7.2, SW8.C (COM); also elsewhere on the board
unnamed: D1.2 (A), R3.2
unnamed: D2.2 (A), R5.2
unnamed: D3.2 (A), R6.2

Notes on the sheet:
From Left to Right looking at the side with the hole

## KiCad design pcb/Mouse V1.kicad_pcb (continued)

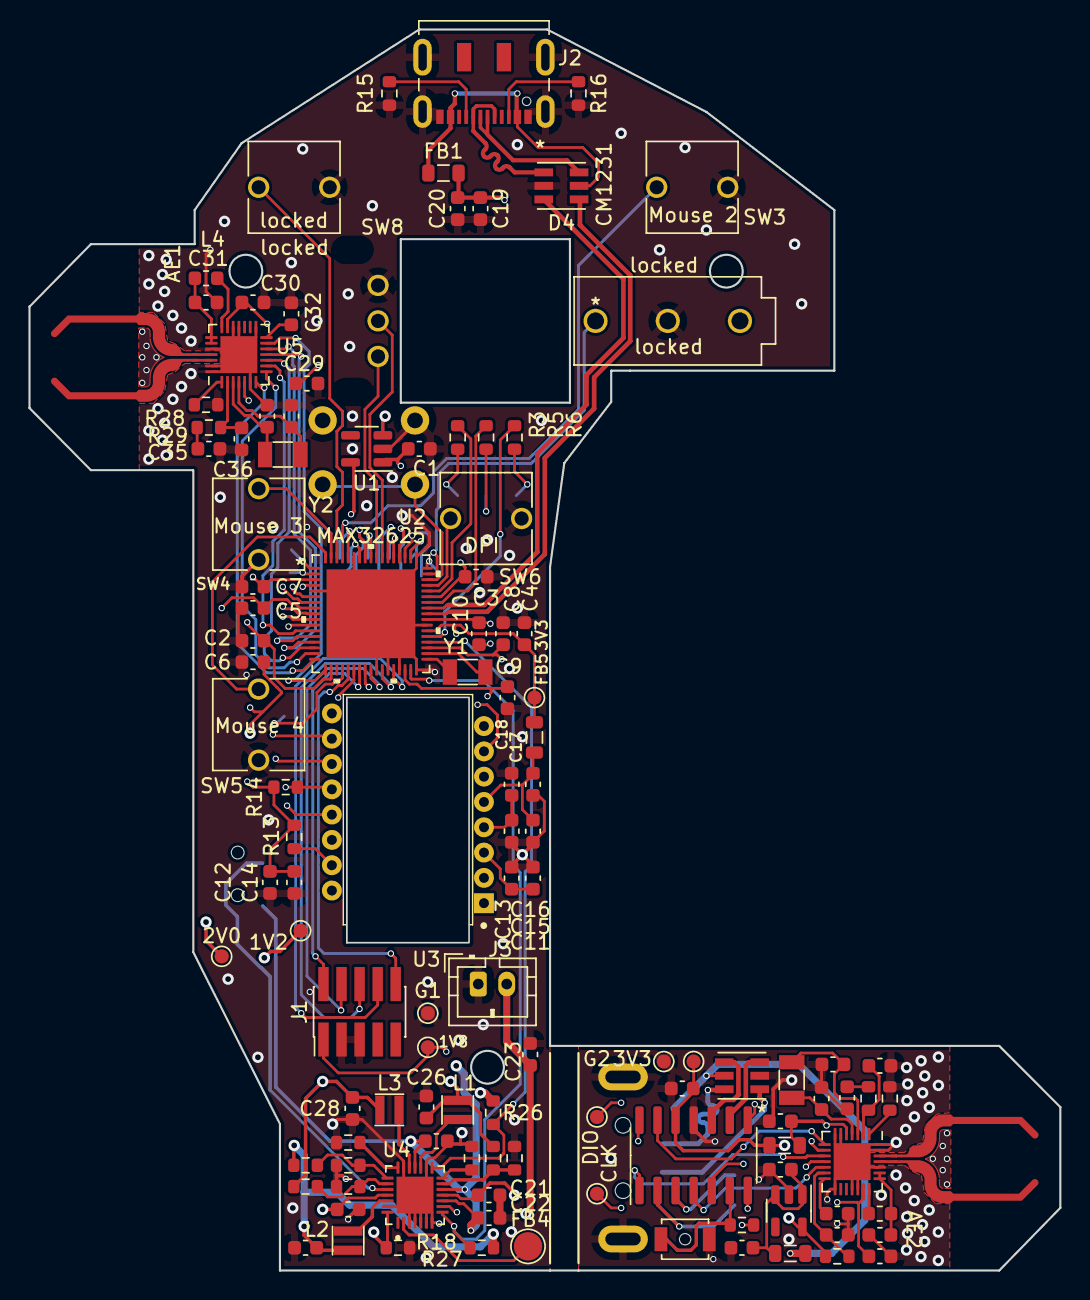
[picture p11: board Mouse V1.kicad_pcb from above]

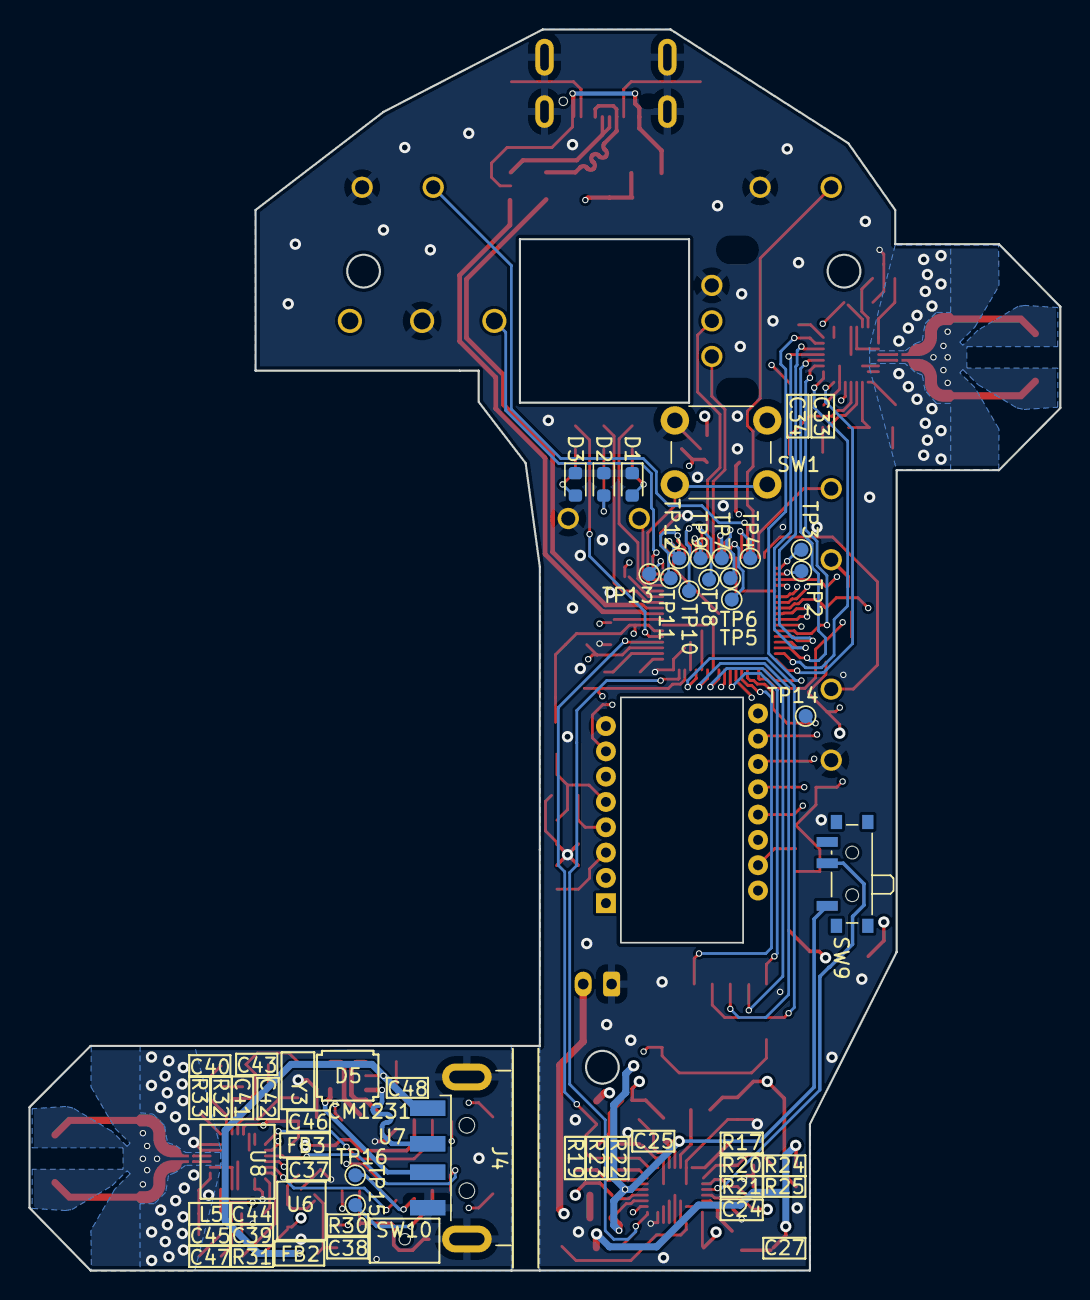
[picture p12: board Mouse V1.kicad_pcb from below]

Board: 4 copper layers, 72.5 x 87.3 mm, 138 parts (21 on the bottom side), 117 nets.

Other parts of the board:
3V3#2: 3.3V Test Point; TestPoint_Pad_D1.0mm
CLK: TestPoint; TestPoint_Pad_D1.0mm
DIO: TestPoint; TestPoint_Pad_D1.0mm
locked: locked; D2F-01L
locked#2: locked; TL59AF100Q

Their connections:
/Microprocessor/Mouse Button 1: locked#2.1; also elsewhere on the board
/Microprocessor/Mouse Scroll Click: locked.1; also elsewhere on the board
GND: locked.2, locked#2.2; also elsewhere on the board
unnamed 41: 3V3#2.1; also elsewhere on the board
unnamed 64: CLK.1; also elsewhere on the board
unnamed 76: DIO.1; also elsewhere on the board

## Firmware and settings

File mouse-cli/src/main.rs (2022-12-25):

use crate::{commands::Commands, keys::map_string};
use clap::Parser;
use commands::{Dist, FunCommand};
use keys::map_keys;
use mouse::Mouse;
use pixels::{Pixels, SurfaceTexture};
use std::{fs::File, time::Instant};
use winit::{
    dpi::LogicalSize,
    event::{Event, VirtualKeyCode},
    event_loop::{ControlFlow, EventLoop},
    window::WindowBuilder,
};
use winit_input_helper::WinitInputHelper;
use y4m::{Frame, Ratio};

mod commands;
mod keys;
mod mouse;

#[derive(Debug, Parser)]
#[clap(author, version, about, long_about = None)]
struct Cli {
    #[clap(long, short, default_value_t = 0x16C0, value_parser)]
    vid: u16,
    #[clap(long, short, default_value_t = 0x27DD, value_parser)]
    pid: u16,
    #[clap(long, short, default_value_t = 0xFF00, value_parser)]
    usage_page: u16,
    #[clap(subcommand)]
    command: Commands,
}

fn main() {
    // Get CLI input
    let cli = Cli::parse();
    // Connect to mouse
    let mouse = Mouse::connect(cli.vid, cli.pid, cli.usage_page);
    // Match command
    match cli.command {
        Commands::SetDpi { dpi } => match dpi {
            Some(dpi) => set_dpi(&mouse, dpi),
            None => read_dpi(&mouse),
        },
        Commands::CpiButtonFunc { keys } => match keys {
            Some(keys) => set_cpi_keys(&mouse, keys),
            None => get_cpi_keys(&mouse),
        },
        Commands::LiftButtonFunc { keys } => match keys {
            Some(keys) => set_lift_keys(&mouse, keys),
            None => get_lift_keys(&mouse),
        },
        Commands::LoremIpsum => lorem_ipsum(&mouse),
        Commands::Save => save_settings(&mouse),
        Commands::Battery => get_battery_voltage(&mouse),
        Commands::SayHi => say_hi(&mouse),
        Commands::Fun { command } => match command {
            FunCommand::AngleSnap { enabled } => match enabled {
                Some(enabled) => set_angle_snap(enabled, &mouse),
                None => get_angle_snap(&mouse),
            },
            FunCommand::Record { path } => record_mouse_frames(path, mouse),
            FunCommand::View => display_mouse_frames(mouse),
        },
        Commands::PollingRate { rate } => set_mouse_polling_rate(rate, &mouse),
        Commands::CalibrateLiftoff => callibrate_mouse_liftoff(&mouse),
        Commands::SetLiftoffDist { dist } => set_mouse_liftoff_dist(dist, &mouse),
    };
}

fn set_mouse_liftoff_dist(dist: Dist, mouse: &Mouse) {
    let dist = match dist {
        Dist::high => true,
        Dist::low => false,
    };
    if let Ok(()) = mouse.set_liftoff_dist(dist) {
        println!("Liftoff dist set!");
    } else {
        println!("Failed to set liftoff dist...");
    }
}

fn callibrate_mouse_liftoff(mouse: &Mouse) {
    if let Ok(()) = mouse.calibrate_liftoff() {
        println!("Mouse Liftoff Calibrated!");
    } else {
        println!("Failed to calibrate mouse liftoff...");
    }
}

fn display_mouse_frames(mut mouse: Mouse) {
    // Start frame reading
    mouse.start_frame_read(0).unwrap();
    let mut done = false;
    // Make window
    const MULT: usize = 20;
    let event_loop = EventLoop::new();
    let mut input = WinitInputHelper::new();
    let window = {
        let size = LogicalSize::new((36 * MULT) as f64, (36 * MULT) as f64);
        WindowBuilder::new()
            .with_title("Mouse Vision")
            .with_inner_size(size)
            .with_min_inner_size(size)
            .build(&event_loop)
            .unwrap()
    };

    let mut pixels = {
        let window_size = window.inner_size();
        let surface_texture = SurfaceTexture::new(window_size.width, window_size.height, &window);
        Pixels::new(36 * MULT as u32, 36 * MULT as u32, surface_texture).unwrap()
    };
    // Run even loop
    event_loop.run(move |event, _, control_flow| {
        if let Event::RedrawRequested(_) = event {
            // Get the current frame
            let frame_data = mouse.read_frame().unwrap();
            // Update frame buffer
            let frame_buffer = pixels.get_frame().chunks_exact_mut(4).enumerate();
            for (i, rgb) in frame_buffer {
                let x = 35 - (i / (36 * MULT)) / MULT;
                let y = (i % (36 * MULT)) / MULT;
                let f_ind = x + y * 36;
                rgb[0] = frame_data[f_ind];
                rgb[1] = frame_data[f_ind];
                rgb[2] = frame_data[f_ind];
                rgb[3] = 255;
            }
            // Render
            if pixels
                .render()
                .map_err(|e| dbg!("pixels.render() failed: {}", e))
                .is_err()
            {
                *control_flow = ControlFlow::Exit;
                return;
            }
        }

        // Handle input events
        if input.update(&event) {
            // Close events
            if input.key_pressed(VirtualKeyCode::Escape) || input.quit() {
                *control_flow = ControlFlow::Exit;
                return;
            }

            // Request a redraw
            window.request_redraw();
        }

        // Handle exit
        if !done && *control_flow == ControlFlow::Exit {
            // Stop Mouse
            mouse.end_frame_read().unwrap();
            // Print
            println!("Done!");
            done = true;
        }
    });
}

fn record_mouse_frames(path: String, mut mouse: Mouse) {
    // Start frame reading
    mouse.start_frame_read(0).unwrap();
    let now = Instant::now();
    let mut iters = 0;
    let mut frames = Vec::new();
    let mut done = false;
    // Make window
    const MULT: usize = 20;
    let event_loop = EventLoop::new();
    let mut input = WinitInputHelper::new();
    let window = {
        let size = LogicalSize::new((36 * MULT) as f64, (36 * MULT) as f64);
        WindowBuilder::new()
            .with_title("Mouse Vision")
            .with_inner_size(size)
            .with_min_inner_size(size)
            .build(&event_loop)
            .unwrap()
    };

    let mut pixels = {
        let window_size = window.inner_size();
        let surface_texture = SurfaceTexture::new(window_size.width, window_size.height, &window);
        Pixels::new(36 * MULT as u32, 36 * MULT as u32, surface_texture).unwrap()
    };
    // Run even loop
    event_loop.run(move |event, _, control_flow| {
        if let Event::RedrawRequested(_) = event {
            // Get the current frame
            let frame_data = mouse.read_frame().unwrap();
            iters += 1;
            // Update frame buffer
            let frame_buffer = pixels.get_frame().chunks_exact_mut(4).enumerate();
            for (i, rgb) in frame_buffer {
                let x = 35 - (i / (36 * MULT)) / MULT;
                let y = (i % (36 * MULT)) / MULT;
                let f_ind = x + y * 36;
                rgb[0] = frame_data[f_ind];
                rgb[1] = frame_data[f_ind];
                rgb[2] = frame_data[f_ind];
                rgb[3] = 255;
            }
            // Save frame
            frames.push(frame_data);
            // Render
            if pixels
                .render()
                .map_err(|e| dbg!("pixels.render() failed: {}", e))
                .is_err()
            {
                *control_flow = ControlFlow::Exit;
                return;
            }
        }

        // Handle input events
        if input.update(&event) {
            // Close events
            if input.key_pressed(VirtualKeyCode::Escape) || input.quit() {
                *control_flow = ControlFlow::Exit;
                return;
            }

            // Request a redraw
            window.request_redraw();
        }

        // Handle exit
        if !done && *control_flow == ControlFlow::Exit {
            // Stop Mouse
            mouse.end_frame_read().unwrap();
            // Get FPS
            let time = now.elapsed().as_millis();
            let fps = f32::round((iters as f32 * 1000.0) / time as f32) as usize;
            // Make file
            let file = File::create(format!("./{path}.y4m")).unwrap();
            // Start encoding
            let mut enc = y4m::encode(36, 36, Ratio::new(fps, 1))
                .with_colorspace(y4m::Colorspace::Cmono)
                .write_header(file)
                .unwrap();
            // Encode
            for frame_data in &frames {
                let frame = Frame::new([&frame_data[..], &[], &[]], None);
                enc.write_frame(&frame).unwrap();
            }
            // Done
            println!("Done! Read {iters} frames into {path}.y4m at {fps}fps");
            done = true;
        }
    });
}

fn set_mouse_polling_rate(rate: u8, mouse: &Mouse) {
    println!("Warning, this function is still really broken, and can only really be used once before you have to reset the mouse (at least on my windows pc).");
    mouse.set_polling_rate(rate);
    println!("Updated polling rate!");
}

fn get_angle_snap(mouse: &Mouse) {
    let val = mouse.get_angle_snap();
    if let Ok(val) = val {
        if val {
            println!("Angle snap is enabled!");
        } else {
            println!("Angle snap is disabled!");
        }
    } else {
        println!("Failed to get angle snap");
    }
}

fn set_angle_snap(enabled: bool, mouse: &Mouse) {
    if let Ok(()) = mouse.set_angle_snap(enabled) {
        if enabled {
            println!("Angle snap was enabled!");
        } else {
            println!("Angle snap was disabled!");
        }
    } else {
        println!("Failed to set angle snap!");
    }
}

fn say_hi(mouse: &Mouse) {
    let hi = mouse.say_hi();
    match hi {
        Ok(hi) => println!("Mouse: {hi}"),
        Err(_) => println!("Failed to get hi :("),
    }
}

fn get_battery_voltage(mouse: &Mouse) {
    // Get voltage
    let voltage = mouse.get_settings().bat_volt();
    println!("Battery voltage is at {voltage} volts");
}

fn get_lift_keys(mouse: &Mouse) {
    // Get keys
    let keys = mouse.get_settings().lift_keys();
    let mods = mouse.get_settings().lift_mods();
    let string = map_keys(mods, keys);
    println!("Currently Lift keys are set to: {string}");
}

fn get_cpi_keys(mouse: &Mouse) {
    // Get keys
    let keys = mouse.get_settings().cpi_keys();
    let mods = mouse.get_settings().cpi_mods();
    let string = map_keys(mods, keys);
    println!("Currently Cpi keys are set to: {string}");
}

fn lorem_ipsum(mouse: &Mouse) {
    // Get Lorem Ipsum
    let ipsum = mouse.lorem_ipsum();
    // Print it
    println!("As the fables say it goes:\r\n\r\n\t{ipsum}.\r\n\r\nAnd so it was told, by such a thing as a mouse.");
}

fn save_settings(mouse: &Mouse) {
    let result = mouse.save_settings();
    match result {
        Ok(_) => println!("Settings saved!"),
        Err(_) => println!("Failed to save settings"),
    }
}

fn set_cpi_keys(mouse: &Mouse, keys: String) {
    let keys = map_string(keys);
    match keys {
        Ok((mods, keys)) => match mouse.set_cpi_keys(mods, keys) {
            Ok(_) => println!("Keys changed succesfully!"),
            Err(_) => println!("Failed to change keys..."),
        }
        Err(err) => match err {
            keys::ParseError::ToManyKeys(num) => println!("{num} is too many keys, you can only have 6 keys at once, excluding modifiers. Failed to update"),
            keys::ParseError::InvalidToken(token) => println!("{token} is an invalid key. Failed to update"),
        }
    }
}

fn set_lift_keys(mouse: &Mouse, keys: String) {
    let keys = map_string(keys);
    match keys {
        Ok((mods, keys)) => match mouse.set_lift_keys(mods, keys) {
            Ok(_) => println!("Keys changed succesfully!"),
            Err(_) => println!("Failed to change keys..."),
        }
        Err(err) => match err {
            keys::ParseError::ToManyKeys(num) => println!("{num} is too many keys, you can only have 6 keys at once, excluding modifiers. Failed to update"),
            keys::ParseError::InvalidToken(token) => println!("{token} is an invalid key. Failed to update"),
        }
    }
}

fn read_dpi(mouse: &Mouse) {
    let dpi = mouse.get_settings().dpi();
    println!("Mouse is set at {dpi} DPI");
}

fn set_dpi(mouse: &Mouse, dpi: u32) {
    mouse.set_dpi(dpi);
    println!("Mouse DPI Set to {}", (dpi / 50) * 50);
}

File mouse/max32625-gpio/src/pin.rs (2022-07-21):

use crate::gpio::GpioReg;

#[derive(Clone, Copy, Debug)]
pub enum Port {
    Port0 = 0,
    Port1 = 1,
    Port2 = 2,
    Port3 = 3,
    Port4 = 4,
}

#[derive(Clone, Copy, Debug)]
pub enum PinNum {
    Pin0 = 0,
    Pin1 = 1,
    Pin2 = 2,
    Pin3 = 3,
    Pin4 = 4,
    Pin5 = 5,
    Pin6 = 6,
    Pin7 = 7,
}

#[derive(Clone, Copy, Debug)]
pub enum PinOutMode {
    // Possible With Value == 0
    HighImpedanceInput = 0x00 | 0,
    OpenDriveLow = 0x00 | 1,
    NormalDriveLow = 0x00 | 5,
    SlowDriveLow = 0x00 | 7,
    FastDriveLow = 0x00 | 9,
    WeakPulldown = 0x00 | 10,
    HighImpedance = 0x00 | 15,
    // Possible With Value == 1
    WeakPullup = 0x10 | 0,
    NormalDriveHigh = 0x10 | 5,
    SlowDriveHigh = 0x10 | 7,
    FastDriveHigh = 0x10 | 9,
    OpenDriveHigh = 0x10 | 11,
}

impl PinOutMode {
    fn get_mode_and_value(self) -> (u8, bool) {
        (self as u8 & 0xF, (self as u8 & 0xF0) == 0x10)
    }
}

#[derive(Clone, Copy, Debug)]
pub enum PinInMode {
    Normal = 0b00,
    Inverted = 0b01,
    Always0 = 0b10,
    Always1 = 0b11,
}

#[derive(Clone, Copy, Debug)]
pub enum PinInterruptMode {
    Disabled = 0b000,
    FallingEdge = 0b001,
    RisingEdge = 0b010,
    EdgeDetect = 0b011,
    ActiveLow = 0b100,
    ActiveHigh = 0b101,
}

#[derive(Clone, Copy, Debug)]
pub enum PinVoltageSupply {
    VDDIO = 0,
    VDDIOH = 1,
}

#[derive(Debug, PartialEq, PartialOrd)]
pub enum GpioError {
    PinAlreadyTaken,
    PinNotFree,
}

pub struct Pin {
    gpio: GpioReg,
    port: Port,
    pin_num: PinNum,
}

impl Pin {
    pub unsafe fn new(gpio: GpioReg, port: Port, pin_num: PinNum) -> Self {
        Self {
            gpio,
            port,
            pin_num,
        }
    }

    pub fn port(&self) -> Port {
        self.port
    }

    pub fn pin_num(&self) -> PinNum {
        self.pin_num
    }

    pub fn set_output(&mut self, mode: PinOutMode) -> Result<(), GpioError> {
        // Make sure we're free and the pin will actually change
        if !self.is_free() {
            return Err(GpioError::PinNotFree);
        }
        // Change the mode and value of the pin
        let (mode, value) = mode.get_mode_and_value();
        let get_mode = |bits| {
            let shift = self.pin_num as u8 * 4;
            (bits & !(0xF << shift)) | ((mode as u32) << shift)
        };
        let get_val = |bits| {
            let shift = self.pin_num as u8;
            (bits & !(0x1 << shift)) | ((value as u32) << shift)
        };
        match self.port {
            Port::Port0 => {
                self.gpio
                    .out_mode_p0
                    .modify(|r, w| unsafe { w.bits(get_mode(r.bits())) });
                self.gpio
                    .out_val_p0
                    .modify(|r, w| unsafe { w.bits(get_val(r.bits())) });
            }
            Port::Port1 => {
                self.gpio
                    .out_mode_p1
                    .modify(|r, w| unsafe { w.bits(get_mode(r.bits())) });
                self.gpio
                    .out_val_p1
                    .modify(|r, w| unsafe { w.bits(get_val(r.bits())) });
            }
            Port::Port2 => {
                self.gpio
                    .out_mode_p2
                    .modify(|r, w| unsafe { w.bits(get_mode(r.bits())) });
                self.gpio
                    .out_val_p2
                    .modify(|r, w| unsafe { w.bits(get_val(r.bits())) });
            }
            Port::Port3 => {
                self.gpio
                    .out_mode_p3
                    .modify(|r, w| unsafe { w.bits(get_mode(r.bits())) });
                self.gpio
                    .out_val_p3
                    .modify(|r, w| unsafe { w.bits(get_val(r.bits())) });
            }
            Port::Port4 => {
                self.gpio
                    .out_mode_p4
                    .modify(|r, w| unsafe { w.bits(get_mode(r.bits())) });
                self.gpio
                    .out_val_p4
                    .modify(|r, w| unsafe { w.bits(get_val(r.bits())) });
            }
        }

        Ok(())
    }
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

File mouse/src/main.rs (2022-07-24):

#![no_std]
#![no_main]
use crate::mouse::MOUSE;
use crate::sensor_driver::Pmw3389Driver;
use crate::usb::{can_pull_hid, can_push_hid, setup_usb};
use cortex_m::asm;
use cortex_m::interrupt::{self as interruptm};
use cortex_m_rt::entry;
use max32625::{Interrupt, CLKMAN, FLC, ICC, PWRSEQ, RTCTMR};
use max32625_gpio::GPIO;
use max32625_timer_basic::Timer;
use mouse::Mouse;
use panic_semihosting as _;
use pmw3389_driver::Pmw3389;

mod flash;
mod mouse;
mod mouse_report;
mod sensor_driver;
mod static_borrow;
mod usb;

const VID: u16 = 0x16C0;
const PID: u16 = 0x27DD;

#[entry]
fn main() -> ! {
    // Wait a bit to let anything catastrophic stay debugable
    cortex_m::asm::delay(24_000_000);

    let peripherals = max32625::Peripherals::take().unwrap();
    let cortex_m_peripherals = cortex_m::Peripherals::take().unwrap();
    let usb = peripherals.USB;
    let sensor_spi = peripherals.SPIM1;
    let pwrman = peripherals.PWRMAN;
    let clkman = peripherals.CLKMAN;
    let icc = peripherals.ICC;
    let pwrseq = peripherals.PWRSEQ;
    let flc = peripherals.FLC;
    let rtctmr = peripherals.RTCTMR;
    let adc = peripherals.ADC;
    let mut gpio = GPIO::new(peripherals.GPIO, &clkman);
    let ioman = peripherals.IOMAN;
    let mut nvic = cortex_m_peripherals.NVIC;
    let main_timer = peripherals.TMR0;
    let sensor_timer = peripherals.TMR1;
    let secondary_timer = peripherals.TMR2;
    let scroll_wheel_timer = peripherals.TMR3;

    init_hardware(&clkman, &icc, &pwrseq, &flc, &rtctmr);

    setup_usb(usb, &pwrman, &clkman, &pwrseq, &adc, &mut nvic);

    let sensor_driver = Pmw3389Driver::new(sensor_spi, sensor_timer, &mut gpio, &ioman, &clkman);
    let sensor = interruptm::free(|_| Pmw3389::init(sensor_driver).unwrap());

    Mouse::new(
        &mut nvic,
        &mut gpio,
        &clkman,
        sensor,
        scroll_wheel_timer,
        adc,
        flc,
    )
    .unwrap();

    main_timer
        .setup_loop_us(500, half_ms_loop, &mut nvic)
        .unwrap();

    secondary_timer
        .setup_loop_ms(10, ten_ms_loop, &mut nvic)
        .unwrap();

    loop {
        asm::nop()
    }
}

pub fn half_ms_loop() -> bool {
    static mut BUF: [u8; 64] = [0; 64];

    if can_push_hid() {
        // SAFTTEY: BUF Only get's mutably borrowed once
        let report = interruptm::free(|cs| unsafe {
            MOUSE
                .borrow(cs)
                .borrow_mut()
                .as_mut()
                .unwrap()
                .get_mouse_report(&mut BUF)
        });
        // We can unwrap the error, since we know we can push
        usb::push_hid(report).unwrap();
    }
    if can_pull_hid() {
        interruptm::free(|cs| {
            let mut buf = [0; 5];
            // We can unwrap the error, since we know we can pull
            let report = usb::pull_hid(cs).unwrap();
            // Index 0 has 0x03, the report ID,
            // which we don't care about
            buf.copy_from_slice(&report[1..]);

            MOUSE
                .borrow(cs)
                .borrow_mut()
                .as_mut()
                .unwrap()
                .interpret_mouse_report(&buf);
        });
    }
    // Continue loop
    true
}

pub fn ten_ms_loop() -> bool {
    // Sanity check USB
    // If there's a nack still pending we should
    // manually trigger the interrupt.
    // It feels improper to do this instead of
    // allowing nacks to gen interrupts, but if
    // you allow it, debug mode generally needs >1ms
    // for making a packet, and nacks generating interrupts
    // give it at most an unterrupted 1ms, so it doesn't work.
    // 10ms is more than enough to form a proper packet and buffer it,
    // while also being barely noticable to the user.
    if usb::is_naking() {
        max32625::NVIC::pend(Interrupt::USB);
    }
    // Get battery level. This shouldn't change very fast, so leaving it be
    // for as long as possible works well.
    interruptm::free(|cs| {
        MOUSE
            .borrow(cs)
            .borrow_mut()
            .as_mut()
            .unwrap()
            .update_battery_level()
    });
    // Continue loop
    true
}

fn init_hardware(clkman: &CLKMAN, icc: &ICC, pwrseq: &PWRSEQ, flc: &FLC, rtctmr: &RTCTMR) {
    // Switch to maximum internal clock speed
    clkman
        .clk_ctrl
        .modify(|_, w| w.system_source_select().variant(1));
    // Enabled cache to improve throughput
    icc.ctrl_stat.modify(|_, w| w.enable().set_bit());
    // Copy power trim values
    const TRIM_FOR_PWR_REG5_PTR: *const u32 = 0x4000_1034 as *const u32;
    const TRIM_FOR_PWR_REG6_PTR: *const u32 = 0x4000_1038 as *const u32;
    const TRIM_FOR_PWR_REG7_PTR: *const u32 = 0x4000_103C as *const u32;
    // Read all 32 bits from the addresses
    let trim_for_pwr_reg5 = unsafe { core::ptr::read_volatile(TRIM_FOR_PWR_REG5_PTR) };
    let trim_for_pwr_reg6 = unsafe { core::ptr::read_volatile(TRIM_FOR_PWR_REG6_PTR) };
    let trim_for_pwr_reg7 = unsafe { core::ptr::read_volatile(TRIM_FOR_PWR_REG7_PTR) };
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

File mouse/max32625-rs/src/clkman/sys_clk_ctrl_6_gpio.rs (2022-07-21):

#[doc = "Register `SYS_CLK_CTRL_6_GPIO` reader"]
pub struct R(crate::R<SYS_CLK_CTRL_6_GPIO_SPEC>);
impl core::ops::Deref for R {
    type Target = crate::R<SYS_CLK_CTRL_6_GPIO_SPEC>;
    #[inline(always)]
    fn deref(&self) -> &Self::Target {
        &self.0
    }
}
impl From<crate::R<SYS_CLK_CTRL_6_GPIO_SPEC>> for R {
    #[inline(always)]
    fn from(reader: crate::R<SYS_CLK_CTRL_6_GPIO_SPEC>) -> Self {
        R(reader)
    }
}
#[doc = "Register `SYS_CLK_CTRL_6_GPIO` writer"]
pub struct W(crate::W<SYS_CLK_CTRL_6_GPIO_SPEC>);
impl core::ops::Deref for W {
    type Target = crate::W<SYS_CLK_CTRL_6_GPIO_SPEC>;
    #[inline(always)]
    fn deref(&self) -> &Self::Target {
        &self.0
    }
}
impl core::ops::DerefMut for W {
    #[inline(always)]
    fn deref_mut(&mut self) -> &mut Self::Target {
        &mut self.0
    }
}
impl From<crate::W<SYS_CLK_CTRL_6_GPIO_SPEC>> for W {
    #[inline(always)]
    fn from(writer: crate::W<SYS_CLK_CTRL_6_GPIO_SPEC>) -> Self {
        W(writer)
    }
}
#[doc = "Field `gpio_clk_scale` reader - Control Settings for CLK6 - Clock for GPIO Ports"]
pub type GPIO_CLK_SCALE_R = crate::FieldReader<u8, u8>;
#[doc = "Field `gpio_clk_scale` writer - Control Settings for CLK6 - Clock for GPIO Ports"]
pub type GPIO_CLK_SCALE_W<'a> = crate::FieldWriter<'a, u32, SYS_CLK_CTRL_6_GPIO_SPEC, u8, u8, 4, 0>;
impl R {
    #[doc = "Bits 0:3 - Control Settings for CLK6 - Clock for GPIO Ports"]
    #[inline(always)]
    pub fn gpio_clk_scale(&self) -> GPIO_CLK_SCALE_R {
        GPIO_CLK_SCALE_R::new((self.bits & 0x0f) as u8)
    }
}
impl W {
    #[doc = "Bits 0:3 - Control Settings for CLK6 - Clock for GPIO Ports"]
    #[inline(always)]
    pub fn gpio_clk_scale(&mut self) -> GPIO_CLK_SCALE_W {
        GPIO_CLK_SCALE_W::new(self)
    }
    #[doc = "Writes raw bits to the register."]
    #[inline(always)]
    pub unsafe fn bits(&mut self, bits: u32) -> &mut Self {
        self.0.bits(bits);
        self
    }
}
#[doc = "Control Settings for CLK6 - Clock for GPIO Ports\n\nThis register you can [`read`](crate::generic::Reg::read), [`write_with_zero`](crate::generic::Reg::write_with_zero), [`reset`](crate::generic::Reg::reset), [`write`](crate::generic::Reg::write), [`modify`](crate::generic::Reg::modify). See [API](https://docs.rs/svd2rust/#read--modify--write-api).\n\nFor information about available fields see [sys_clk_ctrl_6_gpio](index.html) module"]
pub struct SYS_CLK_CTRL_6_GPIO_SPEC;
impl crate::RegisterSpec for SYS_CLK_CTRL_6_GPIO_SPEC {
    type Ux = u32;
}
#[doc = "`read()` method returns [sys_clk_ctrl_6_gpio::R](R) reader structure"]
impl crate::Readable for SYS_CLK_CTRL_6_GPIO_SPEC {
    type Reader = R;
}
#[doc = "`write(|w| ..)` method takes [sys_clk_ctrl_6_gpio::W](W) writer structure"]
impl crate::Writable for SYS_CLK_CTRL_6_GPIO_SPEC {
    type Writer = W;
}
#[doc = "`reset()` method sets SYS_CLK_CTRL_6_GPIO to value 0"]
impl crate::Resettable for SYS_CLK_CTRL_6_GPIO_SPEC {
    #[inline(always)]
    fn reset_value() -> Self::Ux {
        0
    }
}

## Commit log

2022-07-21 Fix lints in mouse
    [mouse.rs]
2022-07-22 Finished work on key updating, and lints/bugs
    [main.rs, mouse.rs, usb.rs]
2022-07-23 Fixed some lints, plus some work on lifting
    [lib.rs, main.rs, mouse.rs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]
2022-07-24 Added battery level, polished commands
2022-07-24 Reworked sensor library, now much better
    [driver.rs, lib.rs, mouse.rs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]
2022-07-27 Making progress on sensor images
2022-07-28 Got sensor output working!
2022-07-29 Got sensor images working fully :)
2022-07-29 Added PCB
    [BOM-Mouse V1.csv, MAX8819CETI_.step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]
2022-08-14 Made sensor imaging commands more intuitive
2022-12-25 New ommands for sensor lift calibration and dist

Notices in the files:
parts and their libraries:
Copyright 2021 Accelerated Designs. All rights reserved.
